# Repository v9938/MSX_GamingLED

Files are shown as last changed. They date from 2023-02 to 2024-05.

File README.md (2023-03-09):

# MSX Gaming LED Cartridge  

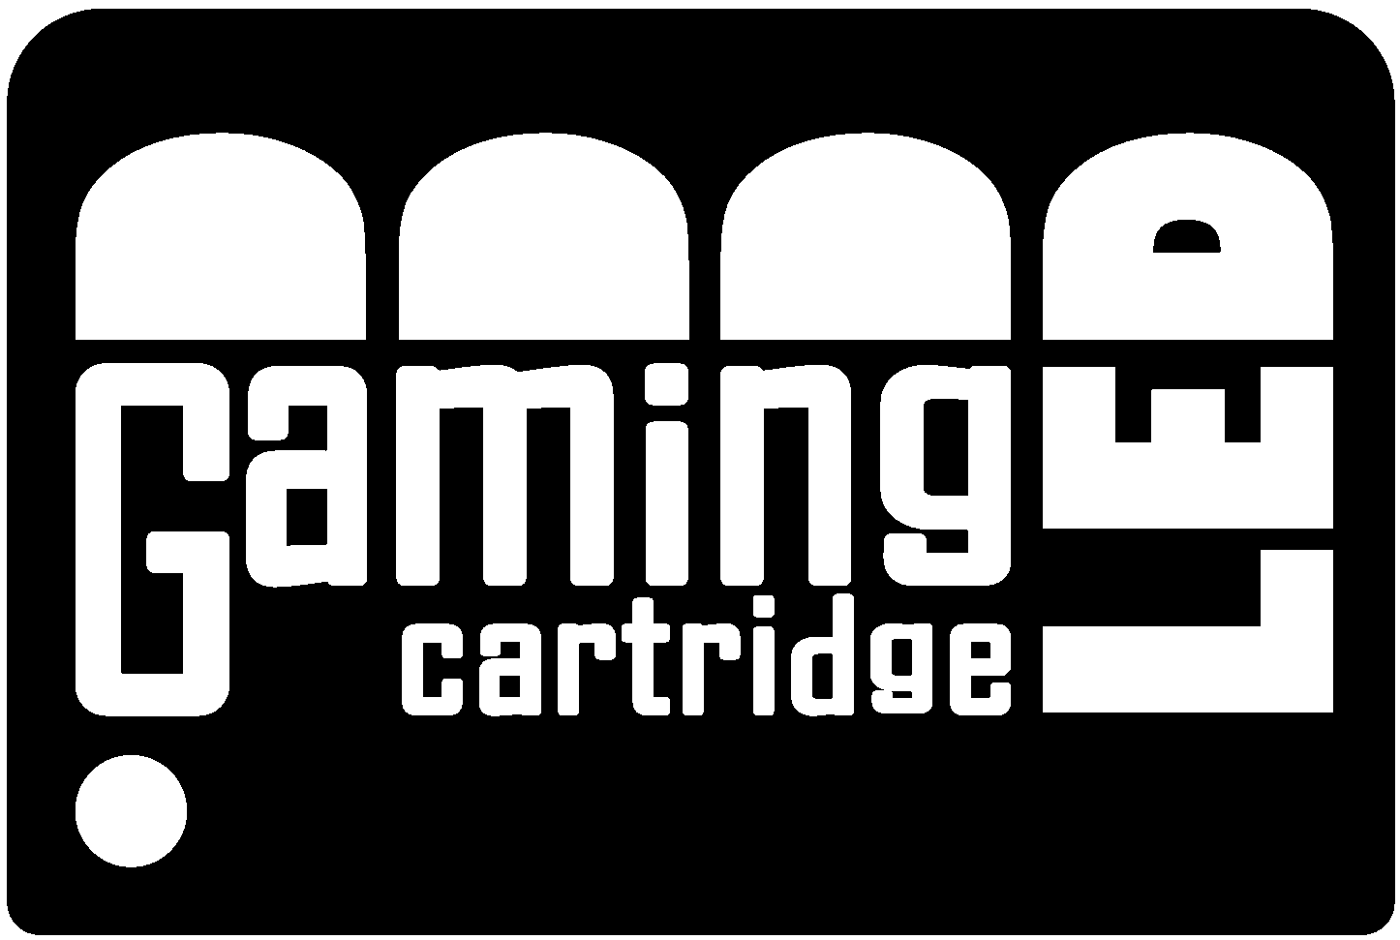
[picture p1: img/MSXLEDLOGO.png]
  

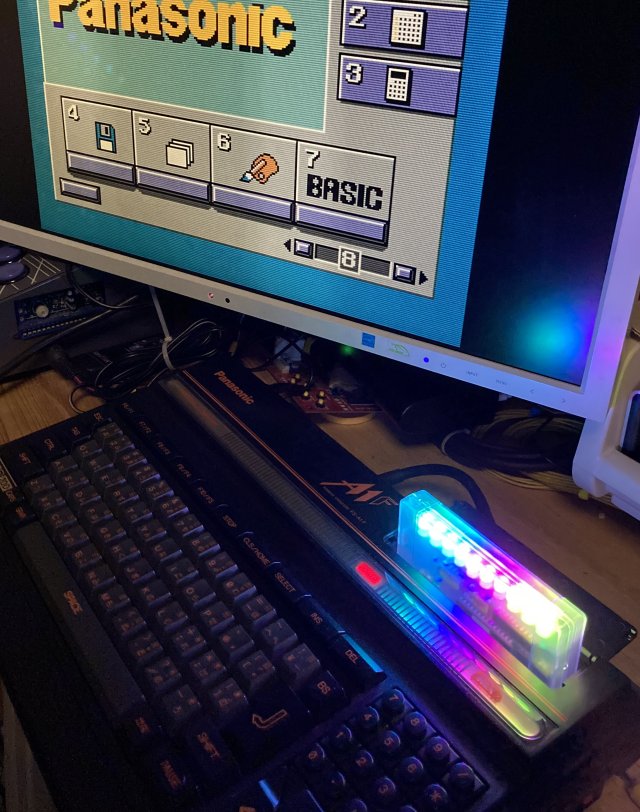
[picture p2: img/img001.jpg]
装置イメージ
  

MSX Gaming LED Cartridgeは10個のRGB LEDを搭載した、Party Nightなカセットです。  
MSX本体から拡張されたBASIC命令により10コのLEDは個別に点灯や色、点滅などのコントロールができ、  
本体のコントロールなしで簡単なアニメーションをさせることができます。

## ■ 使用イメージ

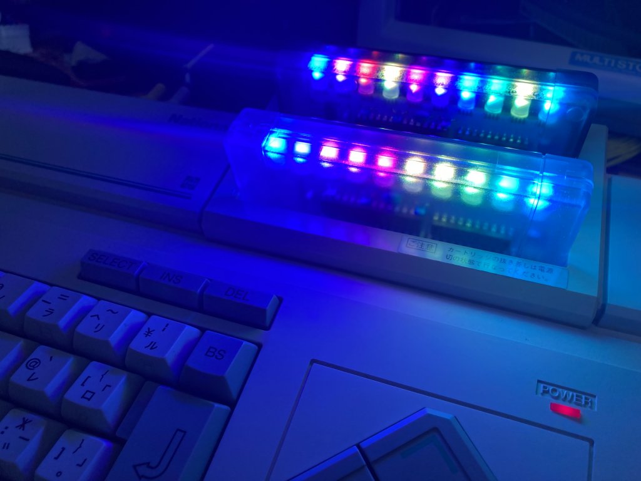
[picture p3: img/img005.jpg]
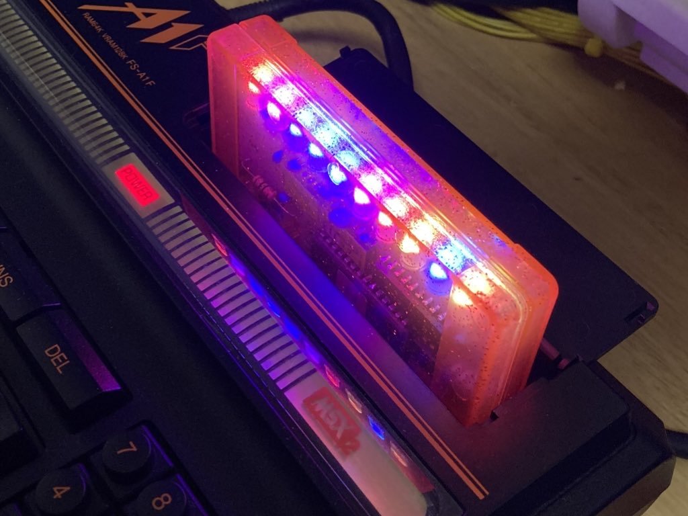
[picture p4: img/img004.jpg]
   
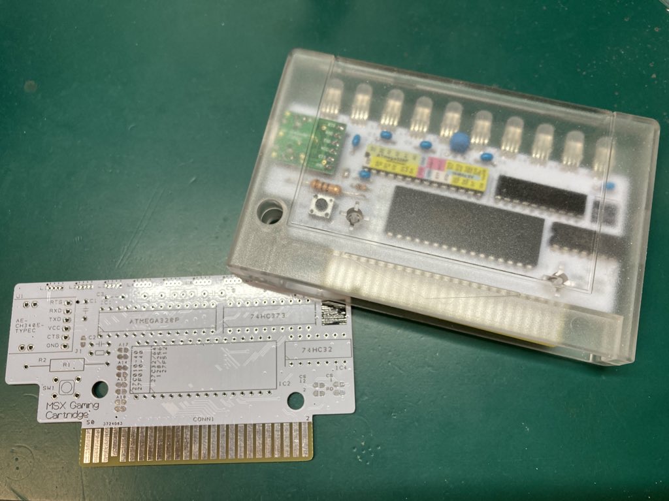
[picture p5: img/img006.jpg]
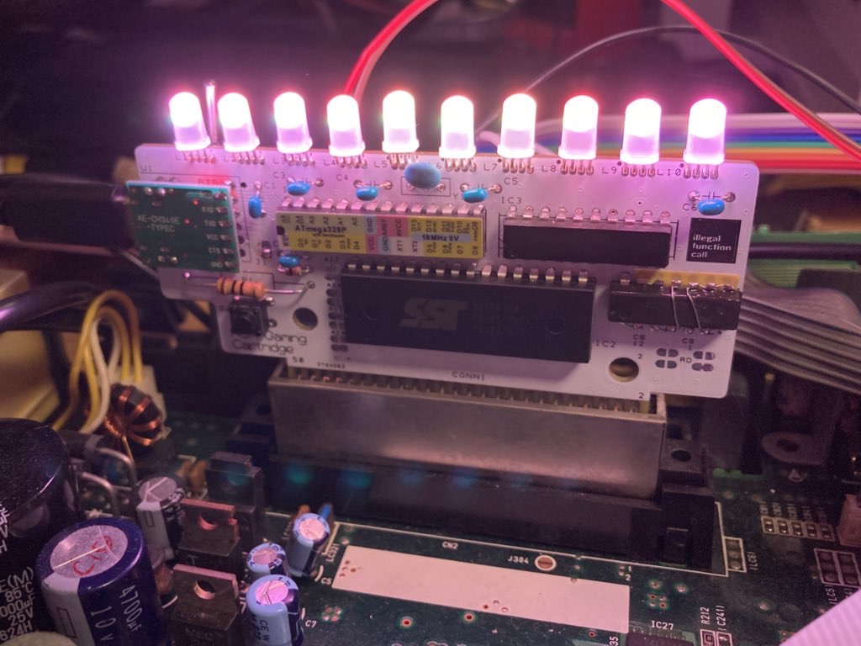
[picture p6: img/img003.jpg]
    

動画については下記URLを参照してください。  
<https://twitter.com/i/status/1623682455151706112>

## ■ 対応ソフトについて   
2023/2月現在下記ソフトが対応しています。

MGSP2(HRA!氏作)  
<https://github.com/hra1129/mgsp2/tree/main/dos2_version>  

## ■ 頒布について   

本製品は半田付けが必要なキット形式の頒布になります。  

Boothおよび家電のKENちゃんにて近日販売予定です。  
(Boothの発送は、週末にまとめて発送になるため、お急ぎの方は他ショップを利用ください)

配布の形態は、下記3形態になります。  

#### フルキット（基板 ＋ プログラム書き込み済みEPROM ＋その他パーツ）
必要なパーツも、すべてセットになったキットです。  

#### 基板＋ROMセット（基板 ＋ プログラム書込済EPROM ＋秋月電子のお買い物メモ）  
基板とプログラム書込済のEPROMのセットです。その他のパーツは秋月電子などで揃える必要があります。  
AVRマイコンへのプログラム書き込みが必要ですのでArduinoの取り扱い経験が必要です。  

#### 基板のみ  
基板単体です。(Boothのみ取り扱い予定)

## ■ 頒布先   

### 家電のKENちゃん  

全パーツ入りセット
<https://www.kadenken.com/view/item/000000001542?category_page_id=ct169>

ROM+基板のみ
<https://www.kadenken.com/view/item/000000001541?category_page_id=ct169>

### Booth: (週１回の発送)  

未定

## ■ BASIC拡張命令およびプログラムからの制御方法について

下記仕様書を参照ください。  

[LED拡張BASIC仕様書](./EXBASIC/led_exbasic.md)  
[MSXLED仕様書](./EXBASIC/msxled_bios.md)

使い方のサンプルは下記を参照してください。  
[BASIC Game Sample](https://github.com/v9938/MSX_GamingLED/tree/main/SampleGame)  
[BASIC/MSX-DOS Sample](https://github.com/v9938/MSX_GamingLED/tree/main/SampleApplication)  

## ■ 組み立て説明書について  
下記を参照ください。  

[組み立て説明書](./AssemblyManual/Assembly.md)

## ■ 対応カートリッジシェルについて
KONAMI基板に対応しているシェルが使用できます。  
当方が頒布しているRGRさんおよび韓国製のCartridge Shellで使える事を確認しています。  
委託先で購入が可能です。  

LEDの点灯が見えないので透明/半透明シェルを推奨します。

## ■ おまけソフト  

MSXTurboRでは[2]キーを押す事で非対応ソフトをR800高速モードで起動させることが可能です。  
ROMカセットで使用する場合、スロット番号の若い方に本カセットを挿入してください。  

## ■ 本機の仕様について

|仕様  | 詳細 |
| - | - |
| 対応規格 | MSX標準スロット規格 |
| 使用LED | PL9823/YF923 x10 |
| 搭載マイコン | Atmel ATMEGA328P (Arduino 5v 16MHz仕様) |
| 定格 | 5V 250mA |

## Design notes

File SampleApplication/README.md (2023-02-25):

# BASIC/MSX-DOS Sample program  
MSXLEDのBASICとMSX-DOSのサンプルプログラムです。

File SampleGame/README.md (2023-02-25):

# BASIC Game Sample program  
MSXLEDのBASICサンプルプログラムです。

あぶり６８００(@aburi6800)さんのGalaxy Zoneを使わせてもらいました。  
<https://github.com/aburi6800/msx-GalaxyZone>

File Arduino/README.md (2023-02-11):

# ATMEGA328Pプログラム
IC1 ATMEGA328Pのプログラムです。Arduino環境で作成されています。  

HEXファイルを書き込み時のFuse設定は下記の通りです。  
FUSE LOW  = 0xFF  
FUSE HIGH = 0xD6  
EXTENED FUSE = 0xFD  
LOCK BIT = 0xCF  

RGB LEDのライブラリとして、Indoor CorgiさんのALED-AddressableRGB-Libraryを使わせていただいています。

[GitHub](https://github.com/IndoorCorgi/ALED-AddressableRGB-Library)  
[Indoor CorgiさんのアドレサブルRGB LED解説](https://www.indoorcorgielec.com/resources/アドレサブルrgb/)  

より複雑な発光パターンを作成したい場合は上記内容を参照ください。

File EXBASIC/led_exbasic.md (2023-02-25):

# 拡張BASICコマンドの解説  
  
##拡張されるBASICのコマンドについて  
Cartridgeに搭載されているROMにて、以下の命令が拡張されます。  
  
各コマンドは処理完了までには数ms程度の時間がかかります。  
命令側でWait処理をいれていません。内部にBufferを持っていて順次処理をしていきます  
が、一度に送信しすぎるとCMDをロストする場合があるので注意してください。  
  
# MSXLED 拡張命令  
## CALL LED_DEBUG(<0-1>)  

### 機能   
LED DEBUG UARTを表示を有効化します。  

### 引数  
0 : デバッグメッセージ OFF  
1 : デバッグメッセージ ON  
  
## CALL LED_OFF  
  
### 機能   
LEDを消灯します。  
  
## CALL LED_DRAW  
  
### 機能   
LEDを描画します。  
  
## CALL LED_POS (\<led location 0-9>)  
### 機能    
描画するLEDのポジションを設定します。左から0,1,2...になります  

### 引数  
led location = 制御するLEDの位置(0-9)

## CALL LED_PT (\<pattern>)  
### 機能    
描画するLEDパターンを定義します。  

### 引数  
pattern = LEDの表示パターン  
0 : パターンSingle ... 全LED単一色の塗り潰しです。  
1 : パターンGrad   ... 色相グラデーションパターン1 (100%パターン)  
2 : パターンSym    ... 色相グラデーションパターン2 (50%パターン)  
3 : パターンPoint1 ... LED1灯のみ光らせるパターン(他は消灯)  
4 : パターンPoint2 ... LED1灯のみデータ更新するパターン(他は前の状態を維持)  

## CALL LED_DEMO (\<pattern>,[End Pattern],[Demo time])  

### 機能    
LEDのデモを実行します。  

### 引数  
pattern = デモパターンの指定  
0 :    パターンSingle ... 全LED単一色の塗り潰しです。  
1 :    パターンGrad   ... 色相グラデーションパターン1 (100%パターン)  
2 :    パターンSym    ... 色相グラデーションパターン2 (50%パターン)  
3 :    パターンPoint1 ... LED1灯のみ光らせるパターン(他は消灯)  
4 :    パターンPoint2 ... LED1灯のみデータ更新するパターン(他は前の状態を維持)  
5～9 : ユーザパターン ... ユーザparameter0-4で保存した値  
  
End Pattern =  終了パターン番号を指定、省略した場合はシングルパターンになります  
  
Demo time = パターンの切り替え時間を指定(0-127)、省略した場合は10秒で切り替わります。  

## CALL LED_DEMOON  
  
### 機能    
現在の設定値でLEDのデモを設定します。  
設定すると、電源を入れておくと次回も同じデモが勝手にスタートします。  
  
## CALL LED_DEMOOFF  
  
### 機能    
LEDのデモ設定を切ります。  
  
## CALL LED_SAVEINIT  
  
### 機能    
LEDのユーザ設定値を初期値に戻します。  
  
## CALL LEDC_RGB (r,g,b)  

### 機能    
RGB値でカラーコードを設定します。システム内部ではHSV方式で管理しているため  
CALL LEDC_HUE/SAT/VALで設定される値は上書きされます。  

### 引数  
r = Red   (0-127)  
g = Green (0-127)  
b = Blue  (0-127)  

## CALL LEDC_HUE(\<hue>)  

### 機能    
HSV方式の色相を設定します。  

### 引数  
hue = 色相 0-360  

## CALL LEDC_SAT (\<sat>)  

### 機能    
HSV方式の色の濃さを設定します。  

### 引数  
sat = 色の濃さ 0-100  
  
## CALL LEDC_VAL (\<val>)  

### 機能    
HSV方式の明るさを設定します。  

### 引数  
val = 明るさ 0-100  
  
## CALL LEDPT_HUE(\<hue>)  

### 機能    
グラデーションパターン時の色相の変化量を指定します。  

### 引数  
hue = 色相 0-360  

## CALL LEDPT_REP (0-10)  
### 機能    
描画するLEDの模様の繰り返し回数を設定します  
  
## CALL LEDTEST (\<val>)  

### 機能    
テスト用当該スロットに1Byteデータ書き込みを実施します。  
通信の仕様上7bit分しか通信できません  

### 引数  
val = 0-127  

## CALL LED_REAL (\<val>)  

### 機能    
クロスチェック用のテストコマンド、  
Debugを有効にすると内部値がUARTに出力されます  

### 引数  
val = 0-360  
  
## CALL LEDA_ON  

### 機能    
今設定しているparameter値に合わせてアニメーションを実行します。  
  
## CALL LEDA_OFF  

### 機能    
アニメーションを停止とします。(LEDは、点灯状態)  
  
## CALL LEDA_HUE (\<mode>,\<val>)  

### 機能    
16ms毎のHUE値の変化量と変化の仕方を設定します。  
  
### 引数  
mode = 
0: 値がMAXなったら0に戻ります  
1: 値がMAXになったマイナスされ、0になると元に戻ります。  

val =  
HUE値 -360.000-360.000  

## CALL LEDA_SAT (\<mode>,\<val>)  

### 機能    
16ms毎のSAT値の変化量と変化の仕方を設定します。  

### 引数  
mode =  
0: 値がMAXなったら0に戻ります  
1: 値がMAXになったマイナスされ、0になると元に戻ります。  

val = SAT値 -100.000-100.000  

## CALL LEDA_VAL (\<mode>,\<val>)  

### 機能    
16ms毎のVAL値の変化量と変化の仕方を設定します。  
  
### 引数  
mode =   
0: 値がMAXなったら0に戻ります  
1: 値がMAXになったマイナスされ、0になると元に戻ります。  

val = VAL値 -100.000-100.000  
  
## CALL LEDA_POS (\<mode>,\<val>)  

### 機能    
16ms毎のPOS値の変化量と変化の仕方を設定します。  
  
### 引数  
mode =  
0: 値がMAXなったら0に戻ります  
1: 値がMAXになったマイナスされ、0になると元に戻ります。  

val = POS値 -100.000-100.000  
  
## CALL LEDPT_SAT (\<val>)  

### 機能    
LEDのグラデーションパターン時のSAT値の変化量を設定します。  
  
### 引数  
val = SAT値の変化範囲指定 0-100
  
## CALL LEDPT_VAL (\<val>)  
  
### 機能    
LEDのグラデーションパターン時のVAL値の変化量を設定します。  

### 引数  
val = VAL値の変化範囲指定 0-100

## CALL LEDPT_AVAL (\<val>)  

### 機能    
LED patternのVAL100%時の明るさを設定します。  

### 引数  
val = 全体の明るさ 0-100

## CALL LEDPT_SAVE (\<val>)  

### 機能    
ユーザパターンをEEPROMに保存します。  
保存した値はDEMOパターン5-9として使用できます。  
  
### 引数  
val = 保存番号0-4   
  
## CALL LEDPT_LOAD (\<val>)  

### 機能    
ユーザパターンをEEPROMからロードします。  

### 引数  
val = 保存番号0-4   
  
## CALL LEDA_PAUSE(\<Value>)  

### 機能    
Animation機能を一次的に停止します。  
停止時のLEDC系とLED_POS値が保存され、再開時の戻します。  
LEDPT系のParameterは保存されないので注意してください。
  
### 引数
val =   
0: Animation動作再開  
1: Animation動作PAUSE  
  
# V1.40以降対応した命令  
## CALL LEDPT_RGB (\<POS>,\<R>,\<G>,\<B>)  

### 機能    
RGB形式でLEDのポジションと色を一括で指定します。  

### 引数  
POS = LEDの位置 0-9  
R/G/B = RGBでの色指定0-127  
※色設定は整数値になります。

## CALL LEDPT_HSV (\<POS>,\<H>,\<S>,\<V>)  

### 機能    
HSV形式でLEDのポジションと色を一括で指定します。  

### 引数  
POS = LEDの位置 0-9  
H = Hue値 (0-360)  
S = Sat値 (0-100)  
V = Val値 (0-100)  
※色設定は整数値になります。

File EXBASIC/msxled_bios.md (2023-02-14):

# BASIC以外から扱う場合の情報  

## LED Gamming Cartridgeの通信フォーマット  
000h 043h 000h CMD番号 ... の順番でこのCartridgeのスロットに書き込むことで実行する。  
000hの部分はbit0を0のデータであれば何でも良いです。  

書き込みアドレスはBIOSでは07F00hを使っています。  
回路上はアドレスをデコードをしていないので書き込みアドレスは適当でも動作します。  

bit0を1にしたデータを取り込む仕様なので、有効データは7bit分です。  
8bit分のデータを送信する場合は ([bit6-0],1),(000000b,[bit7],1)に分けて送信が必要です。  
Data-Data間は10us程度のWaitが必要です、そのためLDIRは使えません。  

各コマンドは処理完了までには数ms程度の時間がかかります。  
内部にBufferを持っていて順次処理をしていきますが、  
64Byte分なので一度に送信しすぎると、コマンドをロストするので注意してください。  

## LED Cartridgeの識別子  
0x4010～の文字列が'MSXLED"というスロットを探してください。  
当該スロットが本Cartridgeになります。  

## Service Routineについて  
0x4020にCMD送信のServiceルーチンが置いてあります。  
### LEDコマンド送信 (4020h)  

<function>  
LEDCartridgeにコマンドを送信します。  
  
	A   実行するコマンド
	B   コマンドサイズ（送信データサイズ）
	HL  送信CMDバッファーの先頭アドレス  

	破壊されるレジスタ：  すべて  

各コマンドの引数は下記フォーマットでRAM上に置き、HLレジスタに先頭アドレス、  
Aレジスタにはコマンド、Bレジスタに送信データサイズをセットしCALLすれば、LED Cartridgeにコマンドがセットされます。  
送信データは、0-127の数値であることが必要です。ただし、9Byte指定のみ4ByteのBCD floatフォーマットが引数です。

	1byte：無し  
	2byte：'[parameter1(7bit 0-127)]'  
	4byte：'[parameter1(7bit 0-127)] [parameter2(7bit 0-127)] [parameter3(7bit 0-127)]'  
	9byte：'[BCD float数値(4byte)]' ※内部で8Byteに変換します  
	その他：データの並び順に送信します。

## コマンド番号一覧  

|コマンドラベル  | コマンド番号 | 命令長 | 内容 |
| - | - | - | - |
|c_cmd_st | 043h	| - | CMDスタート識別子（Serviceルーチン仕様時は不用）  
|  |  |  |  |
|cl_debugen	|		001h | 1Byte | LED Debug UART On |
|cl_off | 003h | 1Byte | LED OFF/DEMO STOP |
|cl_draw | 005h | 1Byte | LED draw |
|cl_pos | 007h | 2Byte | LED position setting |
|cl_pat | 009h | 2Byte | LED pattern setting |
|cl_eepinit  | 00bh | 1Byte | EEPROM Init |
|cl_demo | 00dh | 4Byte | LED DEMO |
|cl_real | 00fh | 9Byte | LED REAL Test |
|  |  |  |  |
|cl_c_rgb | 011h | 4Byte | RGB Coler code |
|cl_c_hue | 013h | 9Byte | HSV Coler code hue |
|cl_c_sat | 015h | 9Byte | HSV Coler code sat |
|cl_c_val | 017h | 9Byte | HSV Coler code val |
|cl_p_hue | 019h | 9Byte | Gradation Pattern hue step value |
|cl_p_rep | 01bh | 2Byte | LED pattern repeat value |
|cl_a_ena| 01dh | 1Byte | LED Animation enable |
|cl_a_dis | 01fh | 1Byte | LED Animation disable |
|  |  |  |  |
|cl_a_hue | 021h | 9Byte | HSV Animation hue |
|cl_a_sat | 023h | 9Byte | HSV Animation sat |
|cl_a_val | 025h | 9Byte | HSV Animation val |
|cl_a_pos | 027h | 9Byte | HSV Animation pos |
|cl_a_modeh  | 029h | 2Byte | HSV AnimationMode hue |
|cl_a_modes  | 02bh | 2Byte | HSV AnimationMode sat |
|cl_a_modev  | 02dh | 2Byte | HSV AnimationMode val |
|cl_a_modep  | 02fh | 2Byte | HSV AnimationMode val |
|  |  |  |  |
|cl_p_sat	| 031h | 9Byte | Gradation Pattern sat step value |
|cl_p_val	| 033h | 9Byte | Gradation Pattern val step value |
|cl_p_aval	| 035h | 9Byte | Gradation Pattern all val value  |
|cl_ee_set	| 037h | 2Byte | EEPROM Write |
|cl_ee_get	| 039h | 2Byte | EEPROM Read |
|cl_ee_cnf	| 03bh | 1Byte | EEPROM Config set |
|cl_a_pause  | 03dh | 2Byte | AnimationMode pause |
|cl_p_rgb	| 03fh | 5Byte | (V1.3～) Color Parameter set (RGB format) |
|  |  |  |  |
|cl_p_hsv	| 041h | 6Byte | (V1.3～)  Color Parameter set (HSV format) |
|cl_null	| 043h | 1Byte |  (V1.3～) NULL CMD (Start CMDと共通なのでNULLにしている）  |
|cl_p_rgball | 045h | 31Byte |  (V1.4～) ALL Color Parameter set & Draw(RGB)  |
|cl_p_hsvall | 047h | 41Byte |  (V1.4～) ALL Color Parameter set & Draw(HSV) |

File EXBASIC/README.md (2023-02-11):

# 拡張BASICプログラム  
拡張BASICプログラムのソースです。  
コンパイルにはMicrosoft M80/L80が必要です。  

できあがったHEXファイルをEPROMに書き込めば動作しますが、  
現在頒布中のRevB基板では基板の設定都合でEPROMの4000h以降に配置される様に書き込んでください。

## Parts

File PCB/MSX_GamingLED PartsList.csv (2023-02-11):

Ref Name | Mfr. Part No. | Qty | 通販コード | 商品名(秋月電子) | Price | 備考
U1 | 5V USB to Serial Unit | 1 | K-14745 | AE-CH340E-TYPEC | 550 | Arduinoプログラム書き込み時のみ使います。 類似品を持っている場合は購入不要
U1 | Pin Header 6P | 1 | C-05336 | ピンヘッダ （Ｌ型） １×６ （６Ｐ） | 10 | Serialユニットを取り外し式にする場合は必要
IC1 | Microchip ATMEGA328P-PU | 1 | I-12774 | Ａｒｄｕｉｎｏ Ｂｏｏｔｌｏａｄｅｒ書込済 （５Ｖ １６ＭＨｚ仕様） ＡＴｍｅｇａ３２８Ｐ | 400 | Bootloaderが自力で書ける人は単体デバイスでOK
C1-6 | Murata RDER71H104K0K1H03B | 6 | P-13582 | 積層セラミックコンデンサー ０．１μＦ５０Ｖ Ｘ７Ｒ ２．５４ｍｍ （１０個入） | 100
IC4 | 74HC00 | 1 | I-14052 | ４回路２入力ＮＡＮＤ Ｕ７４ＨＣ００Ｌ－Ｄ１４－Ｔ | 20 | I-10856 TC74HC00APでもOK
IC3 | 74HC373 | 1 | I-13348 | ８回路入３ステートラッチ ７４Ｆ３７３ （１０個入） | 100
Y1 | Murata CSTLS16M0X53-B0 | 1 | P-09576 | セラミック発振子（セラロック） コンデンサー内蔵タイプ １６ＭＨｚ | 35
L1-10 | PL9823-F5 | 10 | I-08411 | マイコン内蔵ＲＧＢＬＥＤ ５ｍｍ ＰＬ９８２３－Ｆ５ | 400 | 8mm PL9823-F8でもOK
R2 | Yageo CFR-12JT-52-10K | 1 | R-16103 | カーボン抵抗（炭素皮膜抵抗） １／６Ｗ１０ｋΩ （１００本入） | 100
R1 | TE ROX1SJ100R | 1 | R-07956 | カーボン抵抗（炭素皮膜抵抗） １Ｗ１０Ω （１００本入） | 200 | 1W以上の抵抗を必ず使ってください。
IC2 | TOSHIBA TMM27256AD-20 | 1 | - | TOSHIBA TMM27256AD-20 | 0 | キットに添付(基板だけ購入を除く）
SW1 | OMRON B3F-1020 (Max 7mm height) | 1 | P-11243 | タクトスイッチ アルプス製 ※余分な足を切って使ってください | 10 | オプション： スイッチの高さに注意してください P-03647 タクトスイッチはケースに入らないので注意してください
 |  |  |  | Sub-total: | 1925

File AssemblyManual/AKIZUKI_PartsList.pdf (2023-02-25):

| Ref | 通販コード 秋葉原店棚番号 | 商品名 | Qty | 参考価格 (23’/2) | 備考
□ U1 | K-14745 | 1F売場 05 | AE-CH340E-TYPEC | 1
¥550 類似品を持っている場合は購入不要
□ U1 | C-05336 | 1F 12 売場 キャビネット下段 | ピンヘッダ　（Ｌ型）　１×６　（６Ｐ） | 1
¥10 Serialユニットを取り外し式にする場合は必要
□ IC1 | I-12774 | 1F 30 スチールラック売場 | Ａｒｄｕｉｎｏ　Ｂｏｏｔｌｏａｄｅｒ書込済 （５Ｖ　１６ＭＨｚ仕様） ＡＴｍｅｇａ３２８Ｐ | 1 | ¥400 5V仕様を購入すること Bootloaderが自力で書ける人は単体デバイスでOK
□ C1-6 P-13582 | 1F 22 売場 3段目 | 積層セラミックコンデンサー ０．１μＦ５０Ｖ　Ｘ７Ｒ　２．５４ｍｍ　（１０個入） | 1 | ¥100
□ IC4 | I-14052 | 1F 13 売場 キャビネット下段 | ４回路２入力ＮＡＮＤ Ｕ７４ＨＣ００Ｌ－Ｄ１４－Ｔ | 1 | ¥20 I-10856　TC74HC00APでもOK
□ IC3 | I-13348 | 1F 13 売場 キャビネット下段 | ８回路入３ステートラッチ ７４Ｆ３７３　（１０個入） | 1 | ¥100
□ Y1 | P-09576 | 1F 13 売場 キャビネット下段 | セラミック発振子（セラロック） コンデンサー内蔵タイプ　１６ＭＨｚ | 1 | ¥35
□ L1-10 I-08411 | 1F 25 売場 3段目 | マイコン内蔵ＲＧＢＬＥＤ ５ｍｍ　ＰＬ９８２３－Ｆ５ | 10
¥400 8mm　PL9823-F8でもOK
□ R2 | R-16103 | 1F 15 売場 キャビネット下段 | カーボン抵抗（炭素皮膜抵抗） １／６Ｗ１０ｋΩ　（１００本入） | 1 | ¥100
□ R1 | R-07956 | 1F 14 売場 キャビネット上段 | カーボン抵抗（炭素皮膜抵抗） １Ｗ１０Ω　（１００本入） | 1 | ¥200 1W以上の抵抗を必ず使ってください。
□ SW1 P-11243 | 1F 08 売場 キャビネット下段 | タクトスイッチ　アルプス製 ※余分な足を切って使ってください | 1 | ¥10 スイッチの高さに注意してください P-03647 タクトスイッチはケースに入らないです。

## 秋月電子でのお買い物リスト

### 見つからない部品は店員さんに場所を聞きましょう

詳細を見たい場合はこちらを参照

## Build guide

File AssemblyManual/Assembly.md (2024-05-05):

# MSX Gaming LED Cartridge 組み立てマニュアル

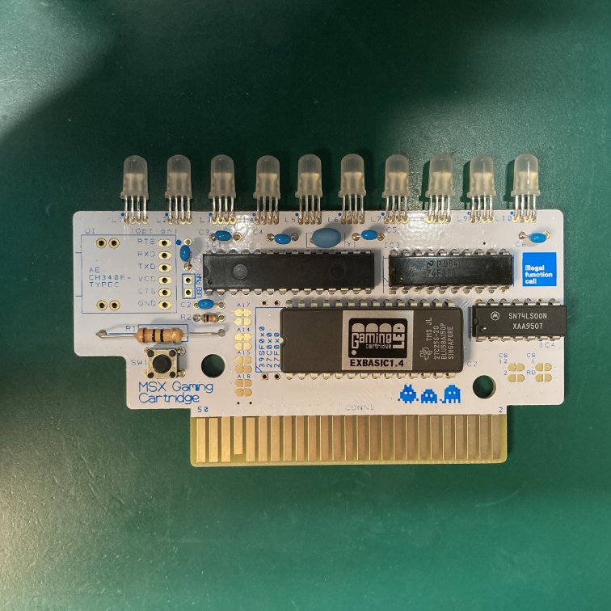
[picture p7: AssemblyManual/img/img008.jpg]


## パーツ一覧

### ■フルキット版  

組み立てに必要なパーツは下記の通りです。  
最低限の動作に必要なパーツは同梱してあります。不足があった場合は連絡お願いします。  
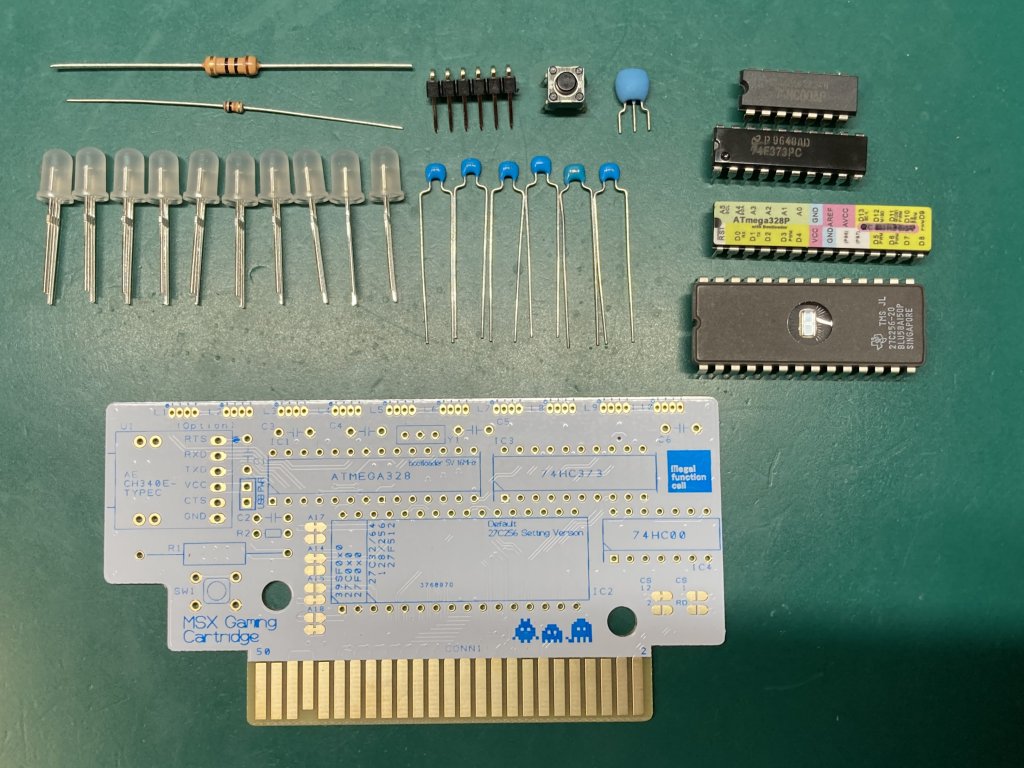
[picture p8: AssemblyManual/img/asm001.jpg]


### 付属部品一覧

|Ref No|Part Name.|Qty|備考|
| :- |  :- |  :- |  :- |
|－|専用PCB|1||
|U1|Pin Header 6P|1|通常は未実装、Serialユニット接続時に使用|
|IC1|Microchip ATMEGA328P-PU|1|Bootloaderとファームウェア書き込み済|
|C1-6|積層セラミックコンデンサー0.1uf 50V|6||
|IC4|TC74HC00AP<BR>(同等品)|1|　|
|IC3|TC74HC373P<BR>(同等品)|1|　|
|Y1|村田 CSTLS16M0X53-B0|1|セラロック１６ＭＨｚ|
|L1-10|PL9823-F5|10|マイコン内蔵RGB LED 5mm |
|R2|100KΩ 1/6W|1||
|R1|10Ω 1W |1|　|
|IC2| 27C256または27C128<BR>(同等品) |1|拡張BASIC書き込み済
|SW1| OMRON B3F-1020 |1|

### ■ 基板＋EPROM版

基板の他に書き込みが難しいUV-EPROMが付属しています  

その他、部品は別途購入する必要があります。秋月電子で揃える事が可能です。  
通販コードを明記してありますので通販で揃えても良いと思います。  

AVRマイコンへのファームウェア書き込みが必要なのでArduinoの実行環境とUSBシリアルユニット必要です。  
また、Arduino Bootloaderの事前書き込みが必要です。（秋月電子では書き込み済を販売しています）  

### 付属部品一覧

|Ref No|Part Name.|Qty|備考|
| :- |  :- |  :- |  :- |
|－|専用PCB|1||
|IC2| 27C256<BR>(同等品) |1|拡張BASIC書き込み済

### 秋月電子お買い物リスト

下記パーツを一括で秋月電子のカートに入れる →[PartsCabi.netのページへ](https://partscabi.net/list/a1651c81-8f59-4dd2-ab42-5e0de5e76d7f)

|Ref No|通販コード|商品名(秋月電子)|Qty|参考価格(2023/2)|備考|
| :- |  :- |  :- |  :- |  :- |  :- |
|U1|K-14745|AE-CH340E-TYPEC|1|￥550|類似品を持っている場合は購入不要|
|U1|C-05336|ピンヘッダ　（Ｌ型）　１×６　（６Ｐ）|1|￥10|Serialユニットを取り外し式にする場合は必要|
|IC1|I-12774|Ａｒｄｕｉｎｏ　Ｂｏｏｔｌｏａｄｅｒ書込済（５Ｖ　１６ＭＨｚ仕様）ＡＴｍｅｇａ３２８Ｐ"|1|￥400|5V仕様を購入すること<BR>Bootloaderが自力で書ける人は単体デバイスでOK|
|C1-6|P-13582|積層セラミックコンデンサー０．１μＦ５０Ｖ　Ｘ７Ｒ　２．５４ｍｍ　（１０個入）|6|￥100||
|IC4|I-14052|４回路２入力ＮＡＮＤ　Ｕ７４ＨＣ００Ｌ－Ｄ１４－Ｔ|1|￥20|I-10856　TC74HC00APもOK|
|IC3|I-13348|８回路入３ステートラッチ　７４Ｆ３７３　（１０個入）|1|￥100||
|Y1|P-09576|セラミック発振子（セラロック）コンデンサー内蔵タイプ　１６ＭＨｚ|1|￥35||
|L1-10|I-08411|マイコン内蔵ＲＧＢＬＥＤ　５ｍｍ　ＰＬ９８２３－Ｆ５|10|￥400| PL9823-F8でもOK|
|R2|R-16103|カーボン抵抗（炭素皮膜抵抗）１／６Ｗ１０ｋΩ　（１００本入）|1|￥100||
|R1|R-07956|カーボン抵抗（炭素皮膜抵抗）１Ｗ１０Ω　（１００本入）|1|￥200|1W以上の抵抗を必ず使ってください。|
|SW1|P-11243|タクトスイッチ　アルプス製<BR>※余分な足を切って使ってください|1|￥10|スイッチの高さに注意してください<BR>P-03647 タクトスイッチはケースに入らないです。"|

## ■ 基板の組み立て

セオリー通り背の低い部品から半田付けしてください。  
ICソケットを使うとケースに入らなくなるので注意してください。  

### 1．カードエッジをマスキングテープなどで端子保護します（推奨）  

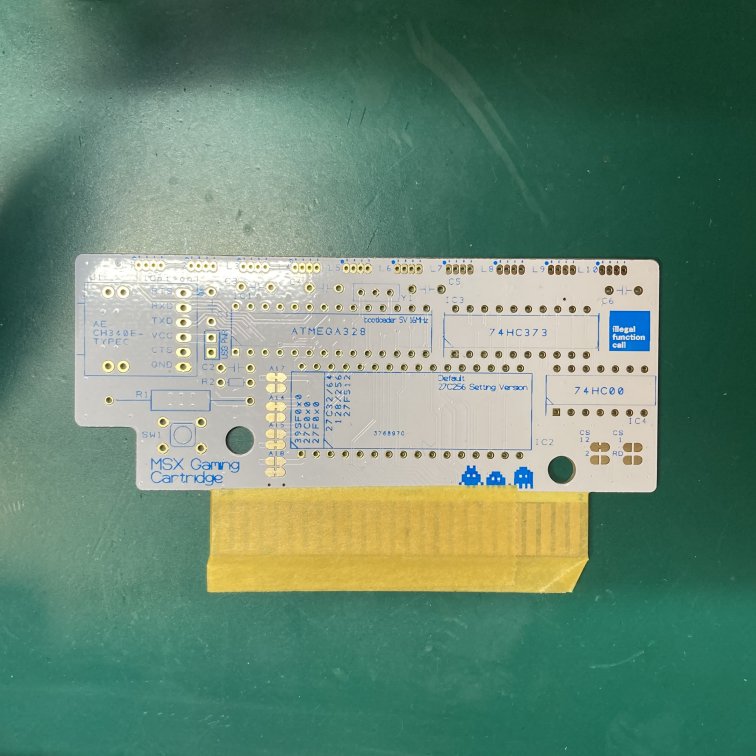
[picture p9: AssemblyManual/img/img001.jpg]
  

### 2．R2/C1-6を実装します  

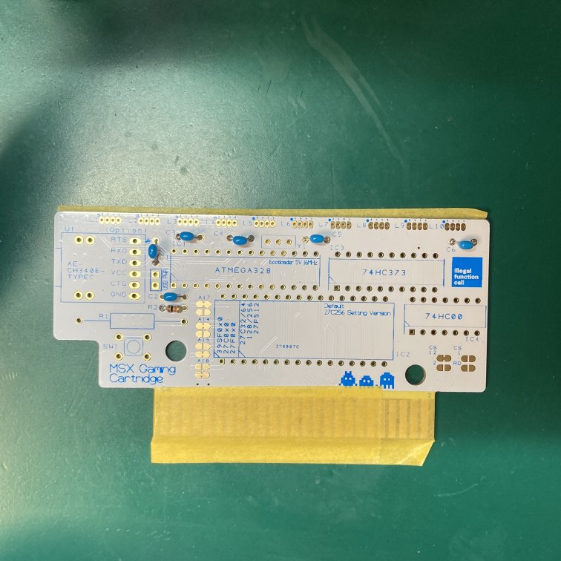
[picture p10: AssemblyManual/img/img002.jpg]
  

### 3．Y1/R1/SW1を実装します  

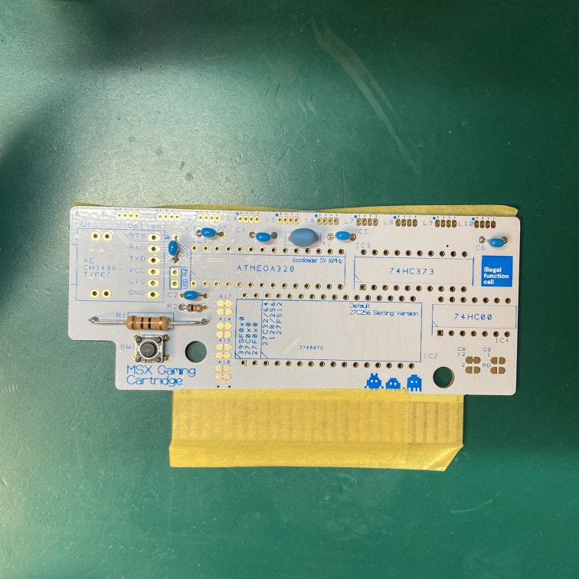
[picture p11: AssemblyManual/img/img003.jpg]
  

R1は多少発熱するので、PCBから多少浮かし実装してください。  
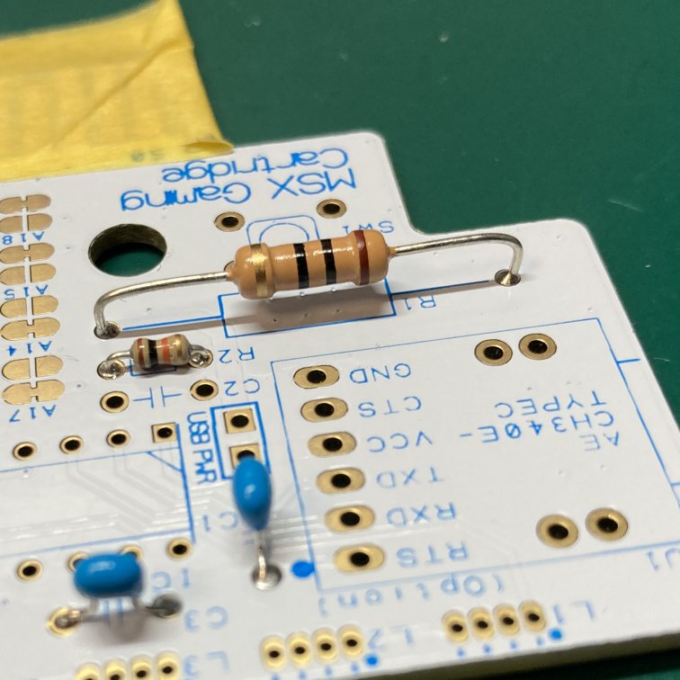
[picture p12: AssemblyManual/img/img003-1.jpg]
  

### 4．IC1-4を実装します  

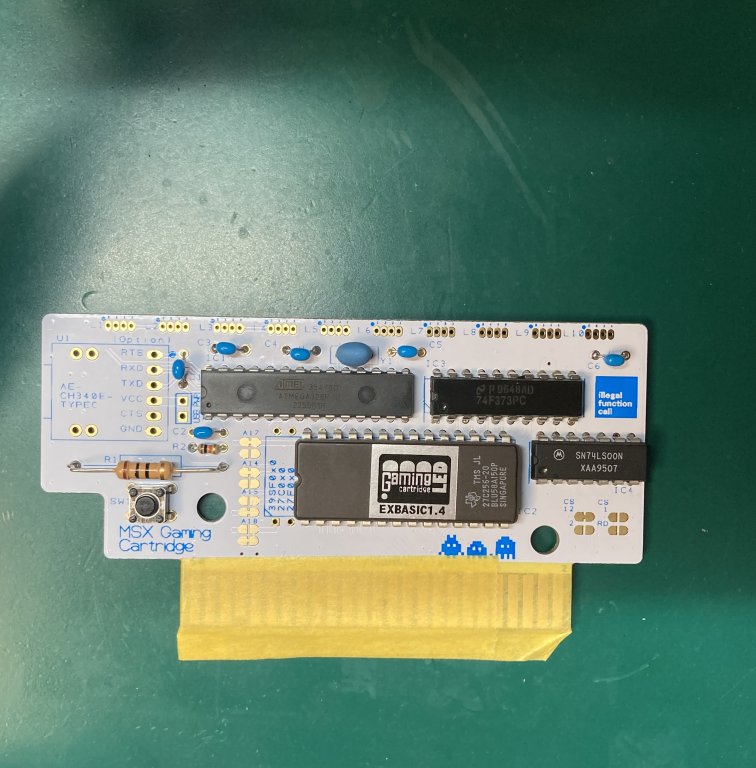
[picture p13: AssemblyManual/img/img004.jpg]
  

### 5．L1-10を実装します  

LEDの実装は後から曲げるやり方(左)と前もって曲げるやり方(右)があります。  
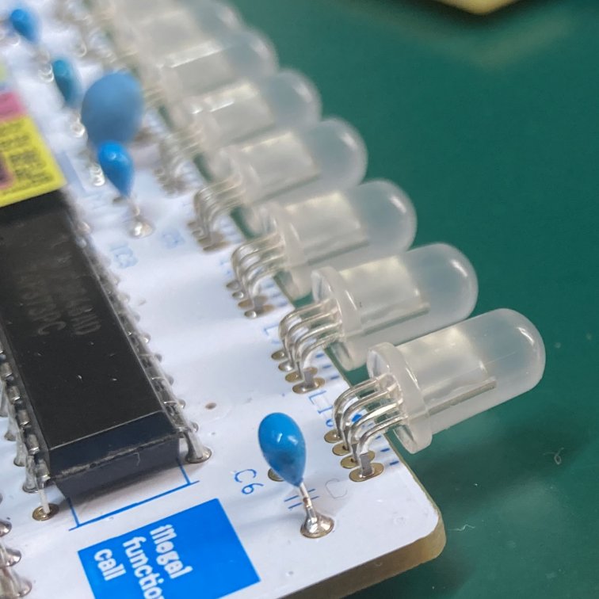
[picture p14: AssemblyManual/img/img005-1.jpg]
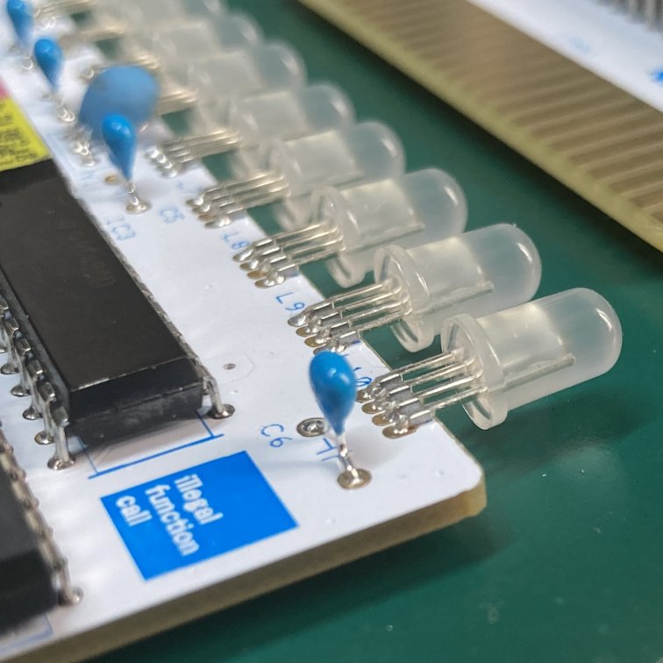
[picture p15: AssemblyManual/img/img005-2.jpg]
  

#### 後から曲げる場合

足が短い方向がDOT側(左)、欠けている側が右になります。  
仕上がりに影響があるので、実装時は膨らみが引っかかる所まで挿入してください。 
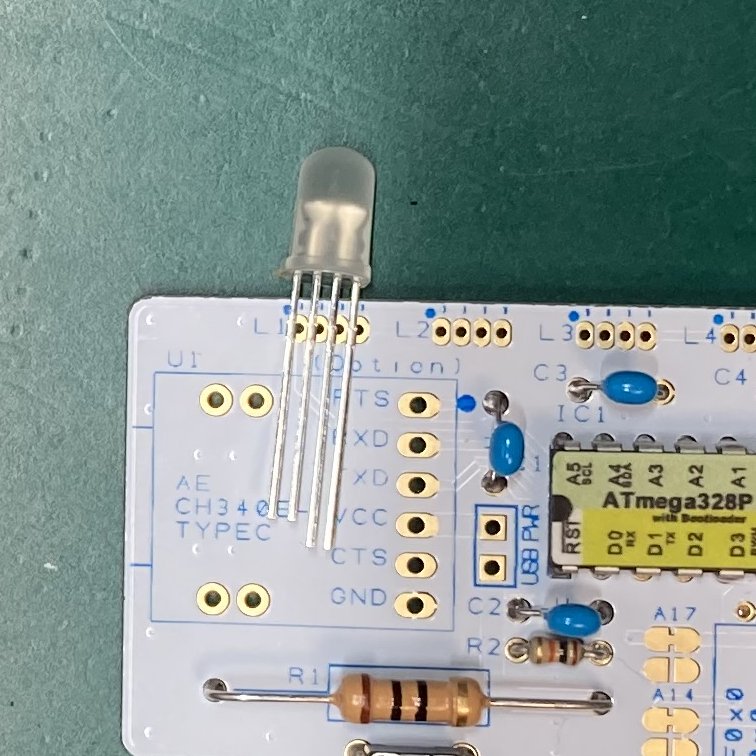
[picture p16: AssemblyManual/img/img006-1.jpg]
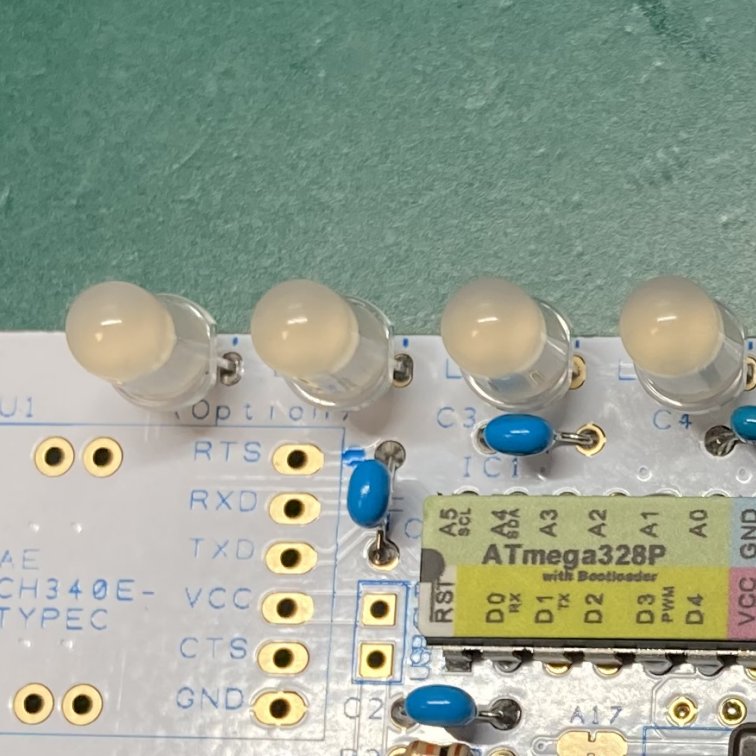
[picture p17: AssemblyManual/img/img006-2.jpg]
    

すべてのLEDが実装したら90度に曲げてください。根元から1mm程度の所で曲がります。  
曲げるときにできるだけ、それぞれの位置が揃う様にすると仕上がりが綺麗です。  
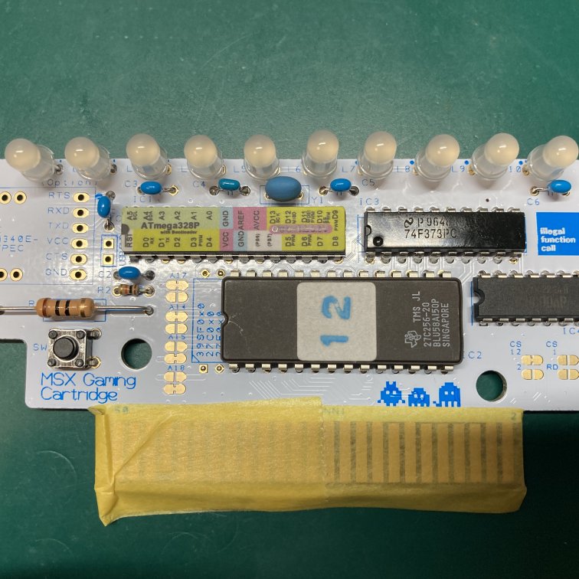
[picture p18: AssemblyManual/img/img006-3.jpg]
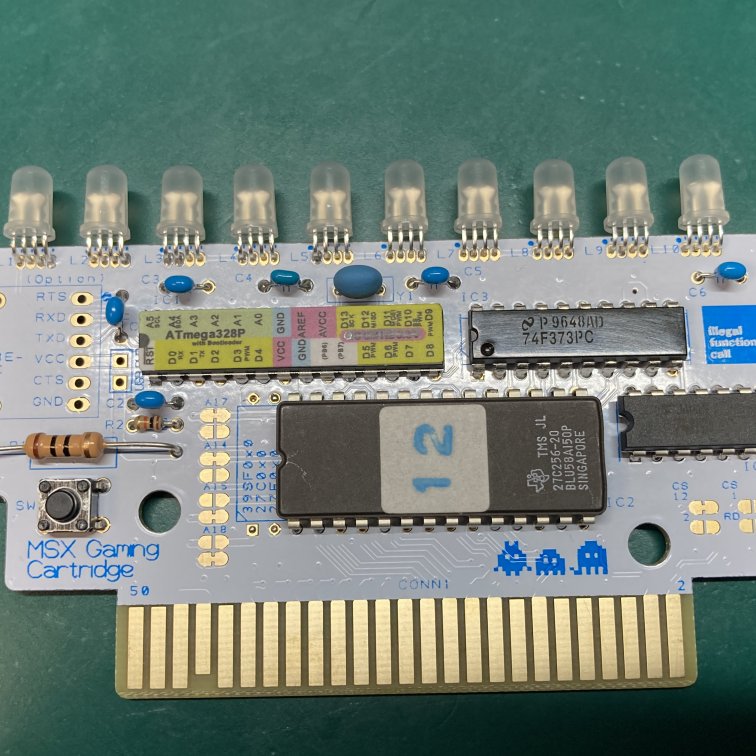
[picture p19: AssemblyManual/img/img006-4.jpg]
      

#### 先に曲げる場合

膨らみがある下であらかじめ足を90度に曲げておきます。  
足が短い方向がDOT側(左)、欠けている側が右になります。  
LEDの足が基板と同じ高さになる様に実装していきます。  
それぞれの位置が揃う様に調整しながら実装すると仕上がりが綺麗です。  
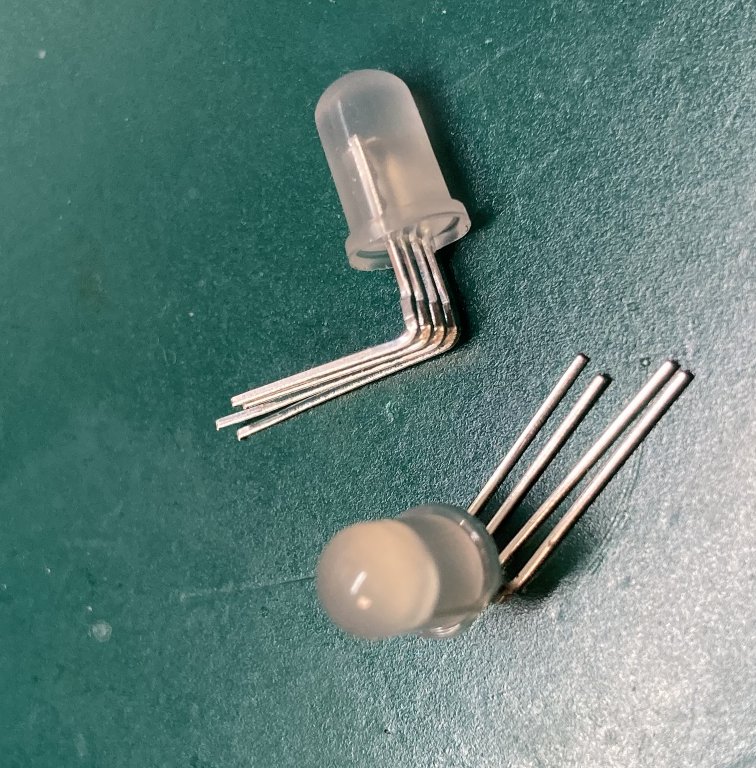
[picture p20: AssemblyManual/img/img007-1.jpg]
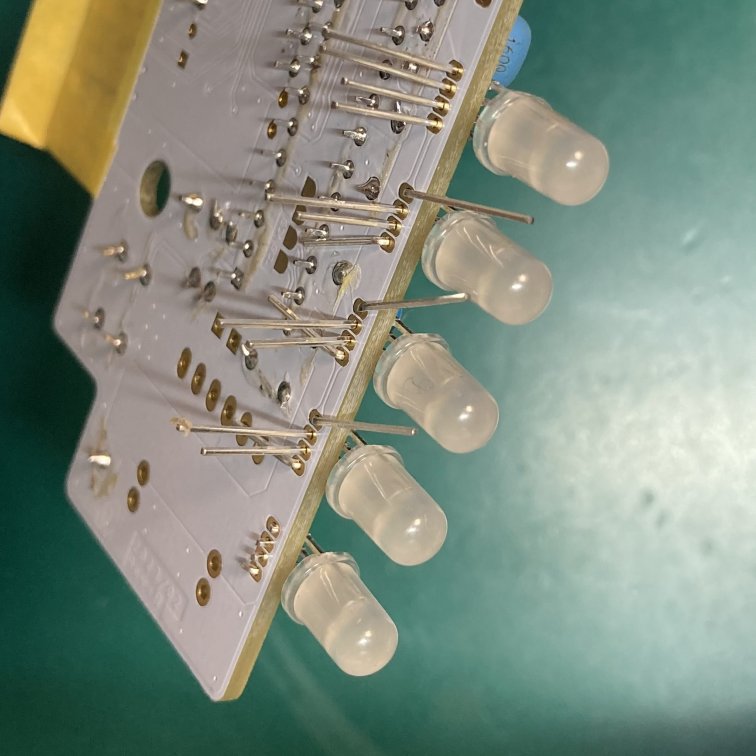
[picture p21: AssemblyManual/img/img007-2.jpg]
     

### 6．U1にシリアルユニットまたはジャンパを実装します(オプション)  

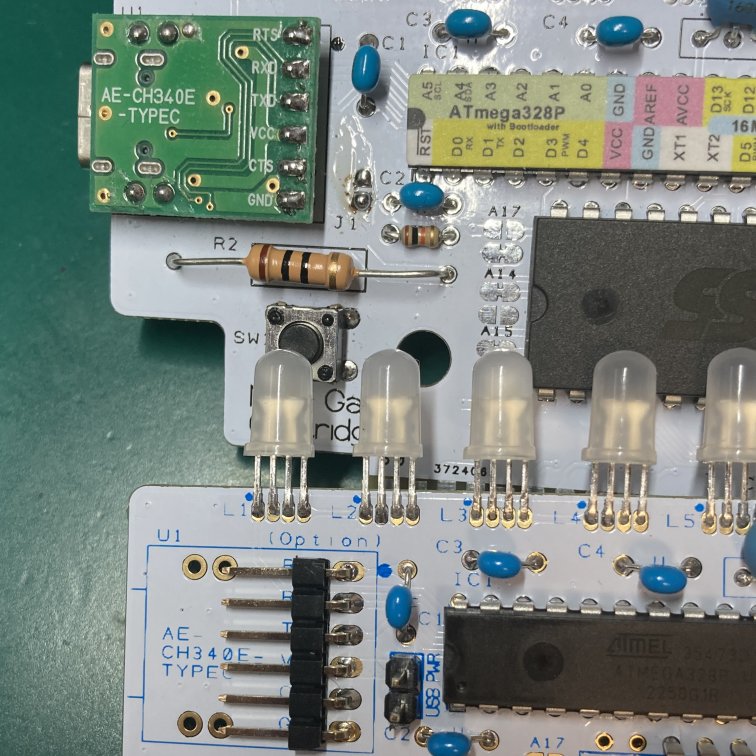
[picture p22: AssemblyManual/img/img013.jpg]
  

### 7．完成！  

組み立て完了です。実機に挿す前に必ずショートチェックを実施してください。 
  

ケースに入れる場合Y1を少し曲げて、ケースに当たらない様にしてください。   

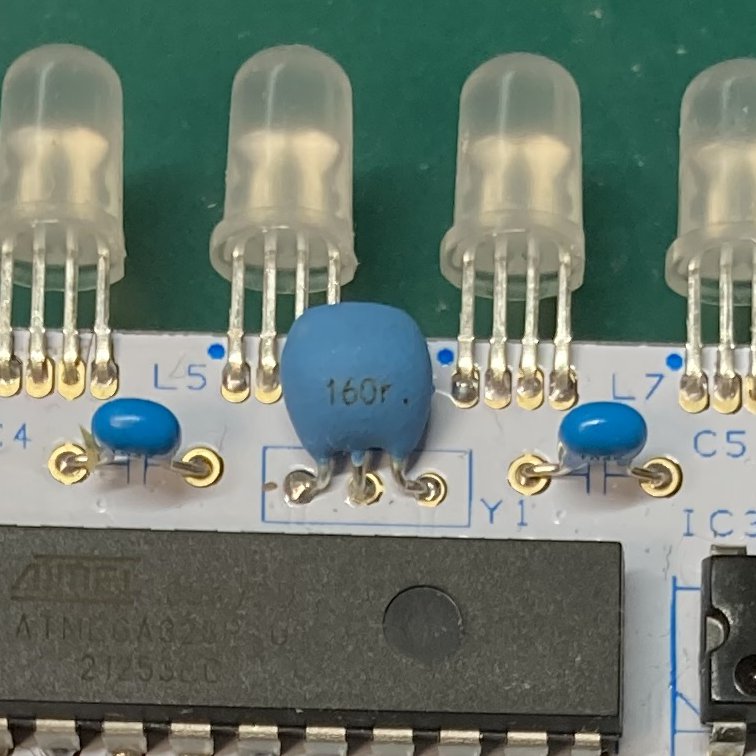
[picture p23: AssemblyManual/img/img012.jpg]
  

## ショートチェック

実機に挿す前にショートが無いか良く確認してください。  
テスタを持っているのであれば、写真の位置でVCC-GNDおよびLED電源のショートチェックを行ってください。  
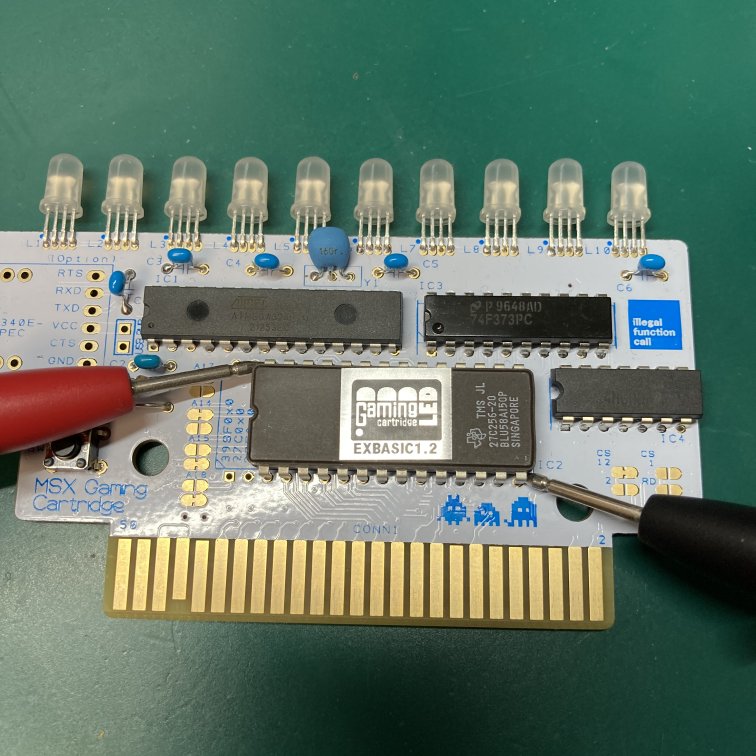
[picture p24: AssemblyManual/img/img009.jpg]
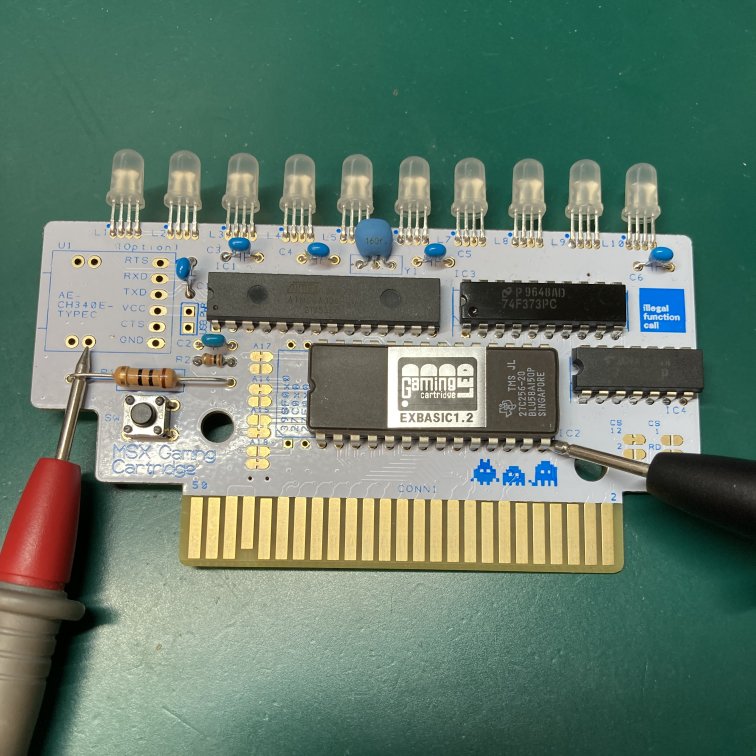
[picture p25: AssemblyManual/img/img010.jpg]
 

## Arduinoスケッチの書き込み (基板＋EPROM版 購入者のみ）

USBシリアルを接続後、MSXに挿入してCartridgeに電源を入れてください。  
(AE-CH340Eを使わない場合はRXD/TXDを接続してください)  

スロットの形状によっては、ケーブルを接続したままで挿入出来ない場合があります。  
その場合は、近傍にあるUSB PWRのジャンパをショートさせUSBから電源供給をしてください。  
（5VがMSXに流れ込むので、書き込み後はオープンに戻してください）

Arduinoのインストールや細かい使い方はここでは割愛します。  
ボード選択はArduino UNO、COMポートはUSBシリアルの番号を選択してください。  
「マイコンボードに書き込む」のアイコンをクリックし、プログラムの書き込みを完了してください。  
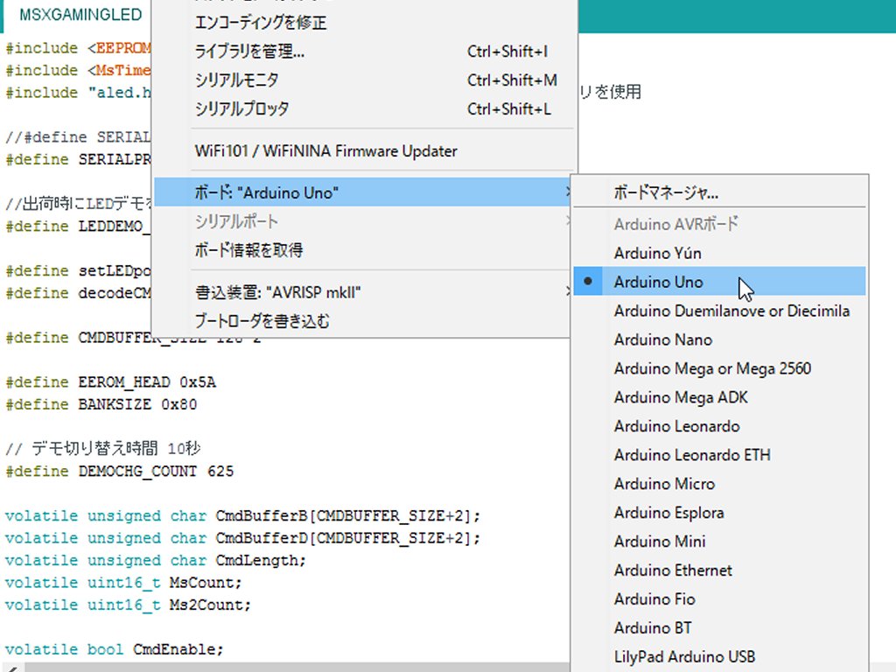
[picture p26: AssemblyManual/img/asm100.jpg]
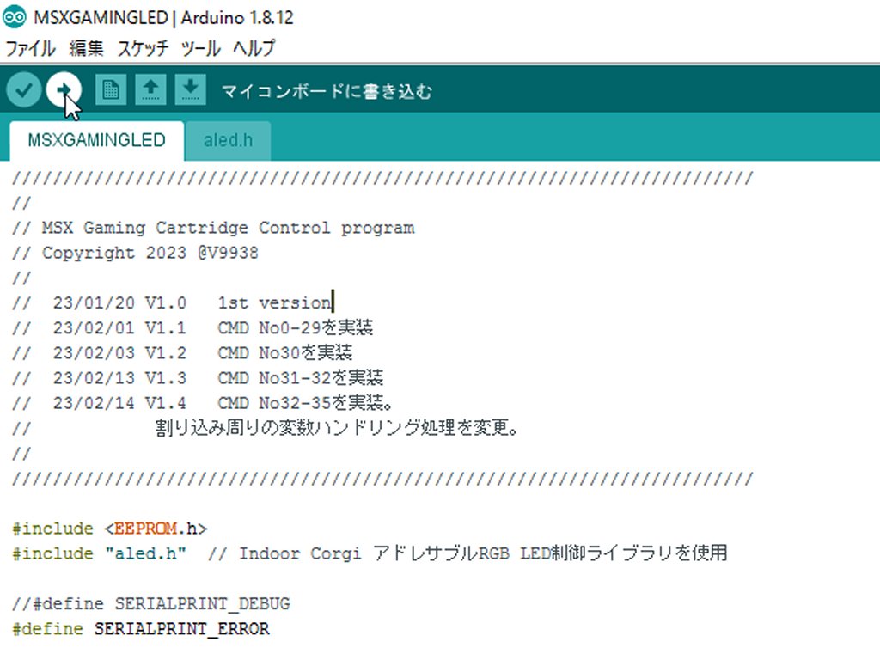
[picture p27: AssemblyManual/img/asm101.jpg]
  

## 動作チェック  

出荷状態であれば、電源を入れると自動的にLEDのデモパターン0～4が実行されます。  

### LEDが光らない/一部が光らない場合

大抵はLED部の半田付け不良です。R1が熱くなる場合は、L1-10のいずれかがショートしています。  
特に、LED部の4つのパッドの真ん中2つがショートしやすいです。そこを確認してみてください。  
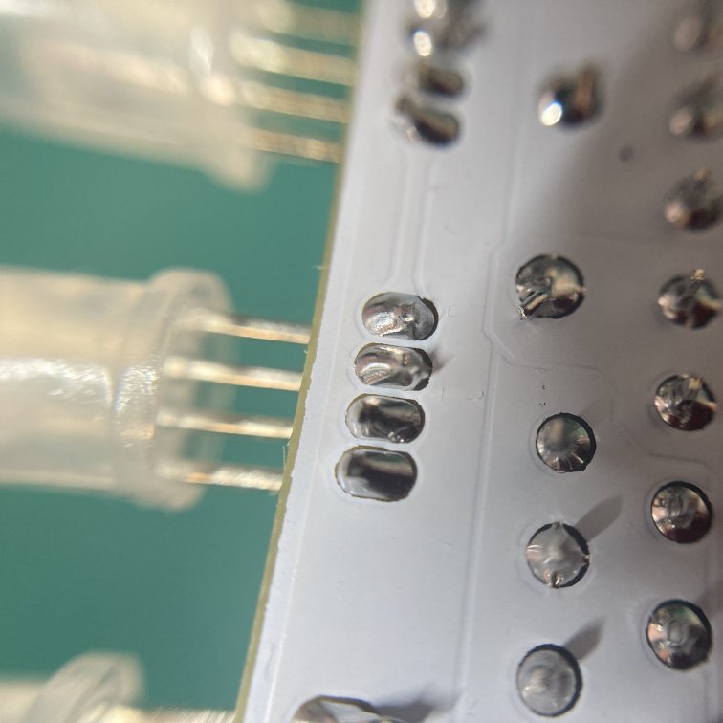
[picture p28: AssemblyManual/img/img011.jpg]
 

### MSX本体が起動しない場合

IC2/IC3/IC4のいずれかの実装不良の可能性があります。

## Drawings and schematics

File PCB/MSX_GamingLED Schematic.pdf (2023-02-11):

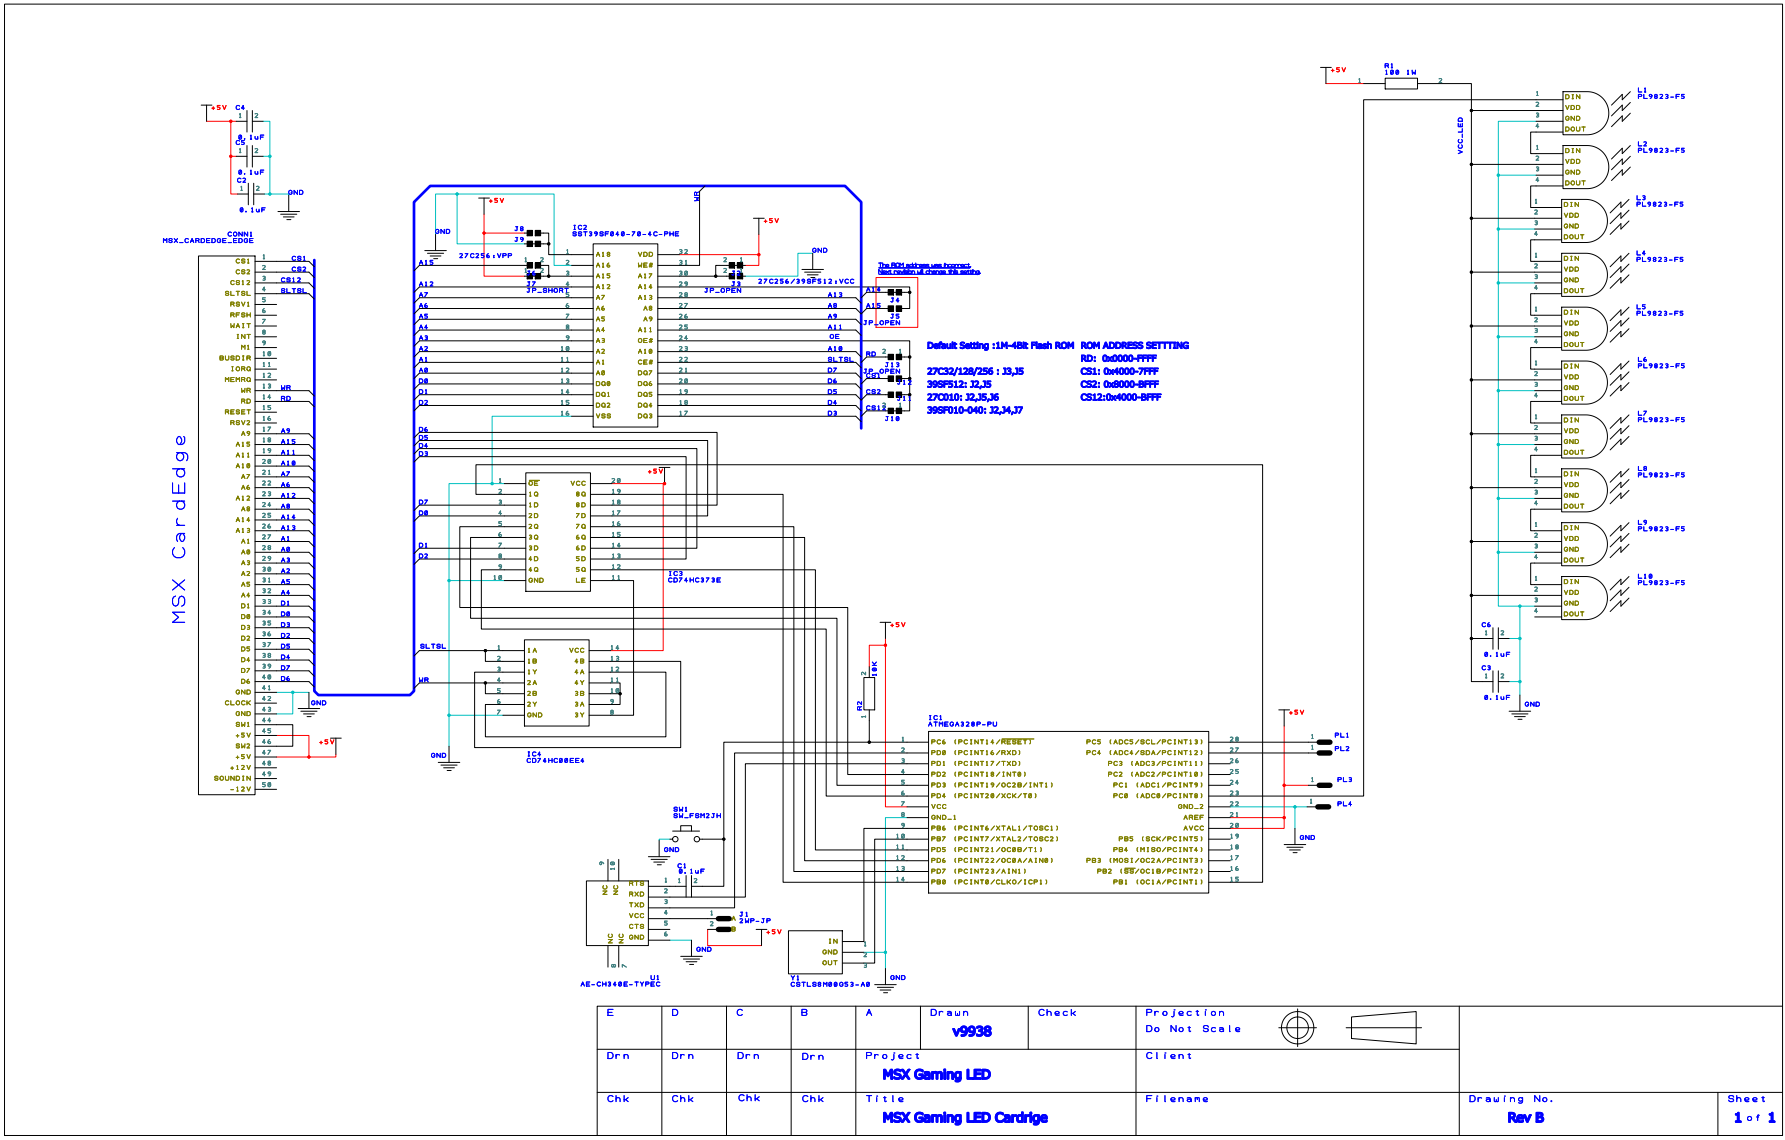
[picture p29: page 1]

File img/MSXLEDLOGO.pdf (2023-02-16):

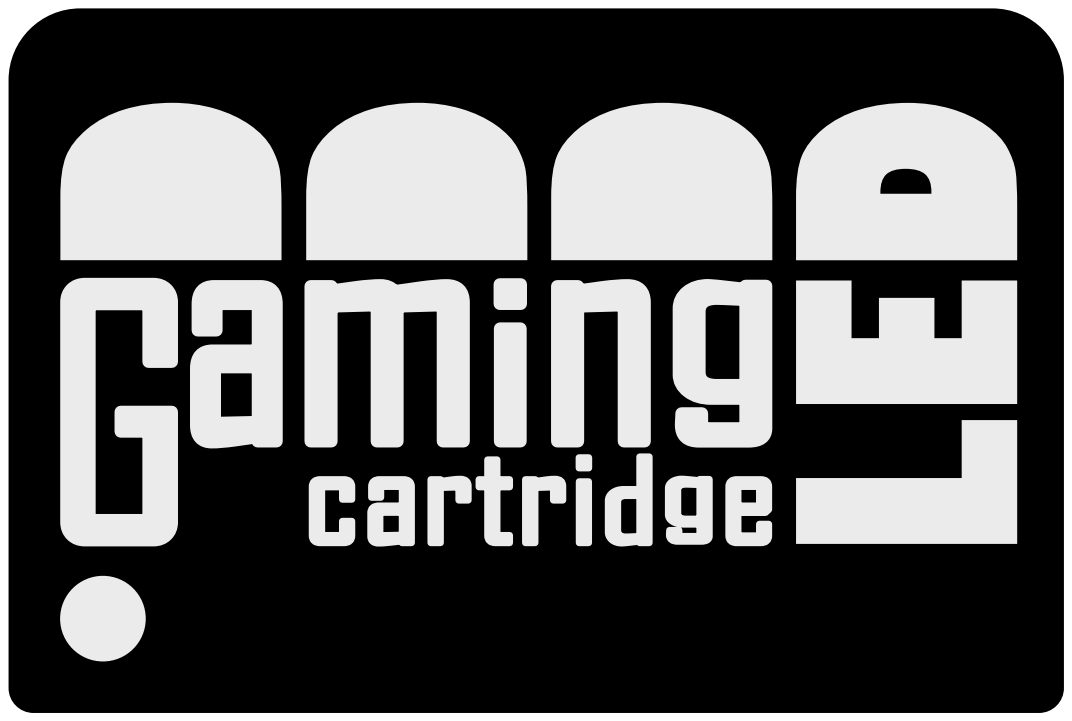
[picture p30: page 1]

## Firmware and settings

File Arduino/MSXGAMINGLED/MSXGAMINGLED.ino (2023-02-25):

////////////////////////////////////////////////////////////////////////
//
// MSX Gaming Cartridge Control program
// Copyright 2023 @V9938
//	
//	23/01/20 V1.0		1st version
//	23/02/01 V1.1		CMD No0-29を実装
//	23/02/03 V1.2		CMD No30を実装
//	23/02/13 V1.3		CMD No31-32を実装
//	23/02/14 V1.4		CMD No32-35を実装。
//						割り込み周りの変数ハンドリング処理を変更。
//	23/02/20 V1.5		LEDAの演算処理の計算式が誤っていたので修正
//
////////////////////////////////////////////////////////////////////////

#include <EEPROM.h>
#include "aled.h"  // Indoor Corgi アドレサブルRGB LED制御ライブラリを使用

//#define SERIALPRINT_DEBUG
//#define SERIALPRINT_ERROR

//出荷時にLEDデモを有効にするか
#define LEDDEMO_DEF_ENABLE

//時間計測用のCMD IN/OUT有効化
//#define CMDINOUT_ENABLE

#define setLEDpos(x) aled.pos = 5.0f + (float) x * 10.0f
#define decodeCMD(i) 0xff & (((unsigned char)(CmdBufferD[i] >> 2)) | (CmdBufferB[i] << 6))

#define errorLedOn		digitalWrite(16,HIGH)
#define errorLedOff		digitalWrite(16,LOW)

#ifdef CMDINOUT_ENABLE
#define cmdLedIn		digitalWrite(15,HIGH)
#define cmdLedOut		digitalWrite(15,LOW)
#else
#define cmdLedIn 
#define cmdLedOut 
#endif


#define CMDBUFFER_SIZE 128*2

#define EEROM_HEAD 0x5A
#define BANKSIZE 0x80

// デモ切り替え時間 10秒
#define DEMOCHG_COUNT 625

//ERROR LED点灯時間 2秒
#define ERRORLED_COUNT 125

volatile unsigned char CmdBufferB[CMDBUFFER_SIZE+2];
volatile unsigned char CmdBufferD[CMDBUFFER_SIZE+2];
volatile unsigned char CmdLength;
volatile uint16_t MsCount;
volatile uint16_t Ms2Count;


volatile bool CmdEnable;
unsigned char CmdHead;
unsigned char CurrentCmdHead;

unsigned char CmdOption;
unsigned char CmdStatus;
unsigned char Cmd;

uint16_t TimeOutMs;
uint16_t ErrorMS;
bool timeOutEnable;

uint16_t ChangeMs;
uint16_t ErrorMs;
uint16_t DemoChangeTime;
unsigned char DemoStartBank;
unsigned char DemoEndBank;

bool DebugOut;
bool LedDemoAll;

uint16_t DemoPattern;
uint16_t DemoCountMs;

bool ChangeEnable;
bool ChangeHueMode;
bool ChangeSatMode;
bool ChangeValMode;
bool ChangePosMode;

bool ResetCmdLength;
bool ResetMsCount;

float ChangeHueMode_sign;
float  ChangeSatMode_sign;
float ChangeValMode_sign;
float ChangePosMode_sign;

//一次保存用ワーク
float pushHue,pushSat,pushVal,pushPos;
uint8_t pushPattern;

// Time Out = 16x6=96ms
#define CMD_TIMEOUT     6

#define WAIT_STARTCMD   0
#define WAIT_CMD        1
#define WAIT_CMDOPTION  2


// COMMAND TABLE

#define MAX_CMD 36

#define cl_debugen  0  // (2Byte) Debug Message
#define cl_off      1  // (1Byte) LED OFF/DEMO STOP  No1
#define cl_draw     2  // (1Byte) LED draw       No2
#define cl_pos      3  // (2Byte) LED position setting No3

#define cl_pat      4  // (2Byte) LED pattern setting  No4
#define cl_eepinit  5  // (1Byte) EEPROM 初期化        No5
#define cl_demo     6  // (4Byte) LED DEMO       No6
#define cl_real     7  // (9Byte) No7 未使用　倍精度テスト用

#define cl_c_rgb    8  // (4Byte) RGB Coler code   No8
#define cl_c_hue    9  // (9Byte) HSV Coler code hue   No9
#define cl_c_sat    10  // (9Byte) HSV Coler code sat   No10
#define cl_c_val    11  // (9Byte) HSV Coler code val   No11

#define cl_p_hue    12  // (9Byte) Gradation Pattern hue step value   No12
#define cl_p_rep    13  // (2Byte) LED pattern repeat value     No13
#define cl_a_enable 14  // (1Byte) LED Animation enable No14
#define cl_a_dis    15  // (1Byte) LED Animation disable No15

#define cl_a_hue    16  // (9Byte) HSV Animation hue    No16
#define cl_a_sat    17  // (9Byte) HSV Animation sat    No17
#define cl_a_val    18  // (9Byte) HSV Animation val    No18
#define cl_a_pos    19  // (9Byte) HSV Animation pos    No19

#define cl_a_modeh  20  // (2Byte) HSV AnimationMode hue   No20
#define cl_a_modes  21  // (2Byte) HSV AnimationMode sat   No21
#define cl_a_modev  22  // (2Byte) HSV AnimationMode val   No22
#define cl_a_modep  23  // (2Byte) HSV AnimationMode pos   No23

#define cl_p_sat	24	// (9Byte) Gradation Pattern sat step value   No24
#define cl_p_val	25	// (9Byte) Gradation Pattern val step value   No25
#define cl_p_aval	26	// (9Byte) Gradation Pattern all val value    No26
#define cl_ee_set   27  // (2Byte) EEPROM Write

#define cl_ee_get   28  // (2Byte) EEPROM Read 
#define cl_ee_cnf   29  // (1Byte) EEPROM Config set
#define cl_a_pause  30  // (2Byte) AnimationMode pause
#define cl_p_rgb    31  // (5Byte) Color Parameter set (RGB format)

#define cl_p_hsv    32  // (6Byte) Color Parameter set (HSV format)
#define cl_null     33  // (1Byte) NULL CMD (Start CMDと共通なのでNULLにしている） No33
#define cl_p_rgball 34  // (31Byte) ALL Color Parameter set & Draw(RGB) No34
#define cl_p_hsvall 35  // (41Byte)  ALL Color Parameter set & Draw(HSV) No35

//Command長テーブル
const unsigned char OptLength[MAX_CMD] = {	0x01,0x00,0x00,0x01, 0x01,0x00,0x03,0x08, 0x03,0x08,0x08,0x08, 
0x08,0x01,0x00,0x00, 0x08,0x08,0x08,0x08, 0x01,0x01,0x01,0x01, 0x08,0x08,0x08,0x01, 0x01,0x00,0x01,0x04, 0x05,0x00,0x1E,0x28};

// アドレサブルRGB制御用のALEDクラスを使う
//  デフォルトは全チャネルに同じデータを送信
//  LED数は使うデバイスに合わせる
ALED aled(CH1, 10,0,0,0,0);

void rgb2hsv(uint8_t red,uint8_t green,uint8_t blue){
	uint8_t max_rgb,min_rgb;

	max_rgb = red;
	if (max_rgb < green) max_rgb = green;
	if (max_rgb < blue) max_rgb = blue; // RGBの中の最大値

	min_rgb = red;
	if (min_rgb > green) min_rgb = green;
	if (min_rgb > blue) min_rgb = blue;

	aled.color.val = ((float)max_rgb/255.0f)*100.0f;

	if (max_rgb != 0.0)  aled.color.sat = ((float)(max_rgb-min_rgb)/(float)max_rgb)*100.0f;
	else aled.color.sat = 0.0f;

	if ((red == green) && (red == blue))aled.color.hue = 0.0f;
	else {
		if (max_rgb == 0)           aled.color.hue = 0.0f;
		else if (max_rgb == red)    aled.color.hue = ((float)(green - blue) / (float)(max_rgb - min_rgb)) * 60.0f;
		else if (max_rgb == green)  aled.color.hue = (2.0f + (float)(blue - red) / (float)(max_rgb - min_rgb)) * 60.0f;
		else                        aled.color.hue = (4.0f + (float)(red - green) / (float)(max_rgb - min_rgb)) * 60.0f;
	}

}
void clearCmd(){
	if (CmdLength == CmdHead)  {

//		noInterrupts();
//		CmdHead = 0;
//		CmdLength = 0;    // CMDバッファーリセット
//		interrupts();

		CmdHead = 0;
		ResetCmdLength = true;		//Lengthリセット要求
	}
	timeOutEnable = false;
	CmdStatus = WAIT_STARTCMD ;
}
void setup() {
// 使うピンを出力に設定
	pinMode(16, OUTPUT);  // Debug port
	pinMode(15, OUTPUT);  // Debug port
	pinMode(14, OUTPUT);  // チャネル1 Pin14, PC0
	pinMode(2, INPUT);   // DAT0
	pinMode(3, INPUT);   // DAT1
	pinMode(4, INPUT);   // DAT2
	pinMode(5, INPUT);   // DAT3
	pinMode(6, INPUT);   // DAT4
	pinMode(7, INPUT);   // DAT5
	pinMode(8, INPUT);   // DAT6
	pinMode(9, INPUT);   // DAT7

	digitalWrite(16,LOW);
	digitalWrite(15,LOW);


//割り込み設定
	EICRA |= (3 << ISC00);    // Trigger on pos edge
	EIMSK |= (1 << INT0);     // Enable external interrupt INT0 = pin3

	TCCR2A = 0;           
	TCCR2B = 0;          
	TCCR2A |= (1 << WGM21);   						//CTC mode
	TCCR2B |= (1 << CS22)|(1 << CS21|(1 << CS20));  //分周1024
	OCR2A   = 250-1;         						//250カウント=16ms
	TIMSK2 |= (1 << OCIE2A);						//TIMER2割り込み有効

	CmdLength = 0;    // CMDバッファーの長さ
	MsCount = 0;      // 1msカウンター（CMD TimeOut管理用）
	CmdHead = 0;
	CmdStatus = WAIT_STARTCMD ;
	timeOutEnable =false;
	ResetCmdLength = true;
	ResetMsCount = true;
	
//attachInterrupt(digitalPinToInterrupt(2),setcmd_func,RISING);

//	MsTimer2::set(16, ms_counter); // 16msカウント
//	MsTimer2::start();




//	sei();                    // Enable global interrupts




// initialize serial and wait for port to open:
	Serial.begin(115200);
//  while (!Serial) {
//    ; // wait for serial port to connect. Needed for native USB port only
//  }
	Serial.println("MSX Gaming LED System");
	Serial.println("firmware rev 1.5(02/20/2023) @v9938");

//LED消灯
	aled.reset(true);

// Temp Buffer初期化
	pushHue = 360.0f;
	pushSat = 100.0f;
	pushVal = 0.0f;
	pushPos = 0.0f;

	noInterrupts();

// アニメーションパターン系初期値
	ChangeMs = 0; 			//更新カウンター
	DemoCountMs = 0;
	DemoPattern = 0;

	setInitParameter();				//初期値設定


	eeprom_get();			//EEPROMの設定値で上書き


	interrupts();
// DEMOモードが有効の場合は値を更新
	if (ChangeEnable) {
		Serial.println("Demo Mode ON");
		setDemoValue(DemoStartBank);
		aled.draw();
	}


	#ifdef SERIALPRINT_ERROR
	if (DebugOut)	Serial.println("User Debug mode ON");
	#endif
	#ifdef SERIALPRINT_DEBUG
	Serial.println("All print mode ON");
	#endif

	Serial.println();


}

void __INT0_vect(){};		//エディタの都合のDummy関数
ISR(INT0_vect)//pin3
{
	if (ResetCmdLength) {
		CmdLength = 0;
		ResetCmdLength = false;
	}
	
	CmdBufferB[CmdLength] = PINB;
	CmdBufferD[CmdLength] = PIND;
	CmdLength++;
}

void __TIMER2_COMPA_vect(){};		//エディタの都合のDummy関数
ISR (TIMER2_COMPA_vect)
//void ms_counter(){
{
	interrupts();     //INT0割り込みは最優先なので有効にしておく
	if (ResetMsCount) {
		MsCount = 0;
		ResetMsCount = false;
	}else{
		MsCount++;
	}
	Ms2Count++;
}
uint16_t marge16bit(uint16_t pos) {
	uint16_t upper,lower;
	uint16_t value;

	upper = 0x7f & ((uint16_t)(decodeCMD(pos+1))>>1);
	lower = 0x7f & ((uint16_t)(decodeCMD(pos+0))>>1);
	value = (upper << 7) | lower;

	return value;

}
float fpow(uint16_t n)
{
	uint16_t i;
	float ret = 1.0;

	for (i = 0; i < n; i++) {
		ret *= 10;
	}

	return ret;
}

//2進化10進数から10進数
float BCDtoDEC(unsigned char* Pointer){
	char bu[10];
	uint8_t b,c,d,e,f,g;
	float dec;
	int8_t s;

	dec = 0.0f;
	b = (*(Pointer+1))>>4;
	c = (*(Pointer+1))&0x0f;
	d = (*(Pointer+2))>>4;
	e = (*(Pointer+2))&0x0f;
	f = (*(Pointer+3))>>4;
	g = (*(Pointer+3))&0x0f;

	dec = (float)b * 100000.0f + (float)c * 10000.0f + (float)d * 1000.0f + (float)e *100.0f + (float)f *10.0f +(float)g;
	#ifdef SERIALPRINT_DEBUG
	Serial.print("\nBCD :  ");
	Serial.println(dec,6);
	#endif
	dec = pow(10.0f,((float)(*(Pointer) & 0x7f)-70.0f))*dec;
	if ((*(Pointer) & 0x80) == 0x80) dec = dec * -1.0f; 
	return dec;
}
float getFloat(){
	unsigned char bcd[4];
	float num;

	bcd[0]=(unsigned char) marge16bit(CmdOption+0);
	bcd[1]=(unsigned char) marge16bit(CmdOption+2);
	bcd[2]=(unsigned char) marge16bit(CmdOption+4);
	bcd[3]=(unsigned char) marge16bit(CmdOption+6);
	num =BCDtoDEC(bcd);

	#ifdef SERIALPRINT_DEBUG
	Serial.print("\ngetFloat :  ");
	Serial.println(num,6);
	#endif

	return num;
}

float getFloat360(){
	float temp;

	temp = getFloat();
//丸め誤差対策
	if (temp >= 360.0f) temp = 360.0f;
	if (temp <= -360.0f) temp = -360.0f;
	return temp;
}
float getFloat100(){
	float temp;

	temp = getFloat();
//丸め誤差対策
	if (temp >= 100.0f) temp = 100.0f;
	if (temp <= -100.0f) temp = -100.0f;
	return temp;
}
void eeprom_setData(int Address){
	int eeAddress = Address;   // 書き込むデータの最初のアドレス


	EEPROM.put(eeAddress, aled.pos);
	eeAddress += sizeof(aled.pos);

	EEPROM.put(eeAddress, aled.repeat);
	eeAddress += sizeof(aled.repeat);

	EEPROM.put(eeAddress, aled.color.hue);
	eeAddress += sizeof(aled.color.hue);

	EEPROM.put(eeAddress, aled.color.sat );
	eeAddress += sizeof(aled.color.sat );

	EEPROM.put(eeAddress, aled.color.val);
	eeAddress += sizeof(aled.color.val);

	EEPROM.put(eeAddress, aled.colorPattern.hue);
	eeAddress += sizeof(aled.colorPattern.hue);

	EEPROM.put(eeAddress, aled.colorPattern.sat );
	eeAddress += sizeof(aled.colorPattern.sat );

	EEPROM.put(eeAddress, aled.colorPattern.val);
	eeAddress += sizeof(aled.colorPattern.val);

	EEPROM.put(eeAddress, ChangeHueMode);
	eeAddress += sizeof(ChangeHueMode);

	EEPROM.put(eeAddress, ChangeSatMode);
	eeAddress += sizeof(ChangeSatMode);

	EEPROM.put(eeAddress, ChangeValMode);
	eeAddress += sizeof(ChangeValMode);

	EEPROM.put(eeAddress, ChangePosMode);
	eeAddress += sizeof(ChangePosMode);


	EEPROM.put(eeAddress, aled.colorChange.hue);
	eeAddress += sizeof(aled.colorChange.hue);

	EEPROM.put(eeAddress, aled.colorChange.sat);
	eeAddress += sizeof(aled.colorChange.sat);

	EEPROM.put(eeAddress, aled.colorChange.val);
	eeAddress += sizeof(aled.colorChange.val);

	EEPROM.put(eeAddress, aled.posChange);
	eeAddress += sizeof(aled.posChange);

	EEPROM.put(eeAddress, aled.pattern);
	eeAddress += sizeof(aled.pattern);

}
void eeprom_setCommon(){
	int eeAddress = 0x10;

	eeAddress += sizeof(DebugOut);

	EEPROM.put(eeAddress, ChangeEnable);
	eeAddress += sizeof(ChangeEnable);
	EEPROM.put(eeAddress, LedDemoAll);
	eeAddress += sizeof(LedDemoAll);
	EEPROM.put(eeAddress, DemoChangeTime);
	eeAddress += sizeof(DemoChangeTime);
	EEPROM.put(eeAddress, DemoStartBank);
	eeAddress += sizeof(DemoStartBank);
	EEPROM.put(eeAddress, DemoEndBank);
	eeAddress += sizeof(DemoEndBank);
	EEPROM.put(eeAddress, DebugOut);
	eeAddress += sizeof(DebugOut);


}
void eeprom_init(){
	int eeAddress = 0x10;

	Serial.println("EEPROM INIT...");

	EEPROM.write(0,EEROM_HEAD);		//HEADER

	EEPROM.put(eeAddress, DebugOut);
	eeAddress += sizeof(DebugOut);

	EEPROM.put(eeAddress, ChangeEnable);
	eeAddress += sizeof(ChangeEnable);
	EEPROM.put(eeAddress, LedDemoAll);
	eeAddress += sizeof(LedDemoAll);
	EEPROM.put(eeAddress, DemoChangeTime);
	eeAddress += sizeof(DemoChangeTime);
	EEPROM.put(eeAddress, DemoStartBank);
	eeAddress += sizeof(DemoStartBank);
	EEPROM.put(eeAddress, DemoEndBank);
	eeAddress += sizeof(DemoEndBank);



	eeprom_setData(BANKSIZE+BANKSIZE*0);	//BANK0
	eeprom_setData(BANKSIZE+BANKSIZE*1);	//BANK1
	eeprom_setData(BANKSIZE+BANKSIZE*2);	//BANK2
	eeprom_setData(BANKSIZE+BANKSIZE*3);	//BANK3
	eeprom_setData(BANKSIZE+BANKSIZE*4);	//BANK4

}

void eeprom_getData(int Address){
	int eeAddress = Address;   // 書き込むデータの最初のアドレス

	EEPROM.get(eeAddress, aled.pos);
	eeAddress += sizeof(aled.pos);

	EEPROM.get(eeAddress, aled.repeat);
	eeAddress += sizeof(aled.repeat);

	EEPROM.get(eeAddress, aled.color.hue);
	eeAddress += sizeof(aled.color.hue);

	EEPROM.get(eeAddress, aled.color.sat );
	eeAddress += sizeof(aled.color.sat );

	EEPROM.get(eeAddress, aled.color.val);
	eeAddress += sizeof(aled.color.val);

	EEPROM.get(eeAddress, aled.colorPattern.hue);
	eeAddress += sizeof(aled.colorPattern.hue);

	EEPROM.get(eeAddress, aled.colorPattern.sat );
	eeAddress += sizeof(aled.colorPattern.sat );

	EEPROM.get(eeAddress, aled.colorPattern.val);
	eeAddress += sizeof(aled.colorPattern.val);


	EEPROM.get(eeAddress, ChangeHueMode);
	eeAddress += sizeof(ChangeHueMode);

	EEPROM.get(eeAddress, ChangeSatMode);
	eeAddress += sizeof(ChangeSatMode);

	EEPROM.get(eeAddress, ChangeValMode);
	eeAddress += sizeof(ChangeValMode);

	EEPROM.get(eeAddress, ChangePosMode);
	eeAddress += sizeof(ChangePosMode);


	EEPROM.get(eeAddress, aled.colorChange.hue);
	eeAddress += sizeof(aled.colorChange.hue);

	EEPROM.get(eeAddress, aled.colorChange.sat);
	eeAddress += sizeof(aled.colorChange.sat);

	EEPROM.get(eeAddress, aled.colorChange.val);
	eeAddress += sizeof(aled.colorChange.val);

	EEPROM.get(eeAddress, aled.posChange);
	eeAddress += sizeof(aled.posChange);

	EEPROM.get(eeAddress, aled.pattern);
	eeAddress += sizeof(aled.pattern);



}

void eeprom_get(){

	int eeAddress = 0x10;

//Header Check
	if (EEPROM.read(0) != EEROM_HEAD) eeprom_init();

	EEPROM.get(eeAddress, DebugOut);
	eeAddress += sizeof(DebugOut);

	EEPROM.get(eeAddress, ChangeEnable);
	eeAddress += sizeof(ChangeEnable);
	EEPROM.get(eeAddress, LedDemoAll);
	eeAddress += sizeof(LedDemoAll);
	EEPROM.get(eeAddress, DemoChangeTime);
	eeAddress += sizeof(DemoChangeTime);
	EEPROM.get(eeAddress, DemoStartBank);
	eeAddress += sizeof(DemoStartBank);
	EEPROM.get(eeAddress, DemoEndBank);
	eeAddress += sizeof(DemoEndBank);

//電源ON時の設定値をロード
	eeprom_getData(BANKSIZE+BANKSIZE*DemoStartBank);			//BANK0 Dataは56Byte
}

void setInitParaAnimation(){
	ChangeEnable = false;		//アニメーションOFF
	LedDemoAll = false;


//アニメーションパターンの設定
//true = 往復 / false=片道
	ChangeHueMode	= false;
	ChangeSatMode	= false;
	ChangeValMode	= false;
	ChangePosMode	= false;

//往復モード時の方向フラグ disable時に戻すこと
	ChangeHueMode_sign	= 1.0f;
	ChangeSatMode_sign	= 1.0f;
	ChangeValMode_sign	= 1.0f;
	ChangePosMode_sign	= 1.0f;

	aled.colorChange.hue = 1.0f;
	aled.colorChange.sat = 0.0f;
	aled.colorChange.val = 0.01f;
	aled.posChange = 1.00f;

#ifdef LEDDEMO_DEF_ENABLE
	ChangeEnable = true;		//アニメーションOFF
	LedDemoAll = true;
#endif

}
void setInitParaDemo(){
// Demo系の初期値設定
	DemoChangeTime = DEMOCHG_COUNT;		//DEMO時間初期値
	DemoStartBank = 0;					//DEMO0
	DemoEndBank = 4;					//DEMO4
	DemoPattern = 0;

}

void setInitParameter(){

	DebugOut = false;			//Debug表示は速度を稼ぐ為にOFF
	setInitParaDemo();			//DEMO系Parameter
	setInitParaAnimation();		//LED Animation Parameter

//初期設定値
	aled.pos = 0.0f;			// LED位置0%
	aled.repeat = 1;			// 全色をLED全部

// 表示する模様の基準の色を指定する
// 今回の例では基準の色は以下の値から変更しない
	aled.color.hue = 0.0f;
	aled.color.sat = 100.0f;
	aled.color.val = 100.0f;

// グラデーション模様の色の変化量を指定する
// 今回の例では以下の虹色模様から変更しない
	aled.colorPattern.hue = 360.0f;
	aled.colorPattern.sat = 0.0f;
	aled.colorPattern.val = 0.0f;

// アニメーションパターン系初期値
	aled.pattern = ALED::patGrad;  // 色相グラデーションパターン1 (100%パターン)
}

void setDemoValue(uint16_t value){

//DEMO番号5～はUSER patternなのでeepromから取得して終わり
	if (value > 4){
		eeprom_getData(BANKSIZE+BANKSIZE*(value-5));			//BANK0 Dataは56Byte
		return;
	}
	
//以下プリセットpattern生成

// グラデーション模様の色の変化量を指定する
// 今回の例では以下の虹色模様から変更しない
	aled.colorPattern.hue = 360.0f;
	aled.colorPattern.sat = 0.0f;
	aled.colorPattern.val = 0.0f;


//アニメーションパターンの設定
//true = 往復 / false=片道
	ChangeHueMode	= false;
	ChangeSatMode	= false;
	ChangeValMode	= true;
	ChangePosMode	= false;

//往復モード時の方向フラグ 必要に応じて戻すこと
//		  ChangeHueMode_sign	= 1.0f;
//		  ChangeSatMode_sign	= 1.0f;
//		  ChangeValMode_sign	= 1.0f;
//		  ChangePosMode_sign	= 1.0f;


//16ms毎の値の変化量設定
	aled.colorChange.hue = 1.0f;
	aled.colorChange.sat = 0.0f;
	aled.colorChange.val = 0.5f;
	aled.posChange = 1.00f;
	aled.pattern = (uint8_t) value;
	
//patternだけ同じだと面白く無いので少し弄る
	if (value == ALED::patSingle) {		// 全体フラッシュ
		aled.colorChange.val = 1.00f;
	}

	if (value == ALED::patGrad) {		// 色相グラデーションパターン1 (100%パターン)
		aled.posChange = 5.00f;
	}

	if (value == ALED::patSym) {		// 色相グラデーションパターン2 (50%パターン)
		aled.posChange = 0.80f;
	}
	if (value == ALED::patPoint1) {		// LED1灯のみ光らせるパターン(他は消灯)
		aled.posChange = 0.50f;
		ChangePosMode	= true;
	}
	if (value == ALED::patPoint2) {		// LED1灯のみデータ更新するパターン(他は前の状態を維持)
		aled.posChange = 2.00f;
		ChangePosMode	= true;
	}
}

void debugDoCMD_InParameter(){

	unsigned char bcd[4];
	char buf[100];
	unsigned char* ddd;
    float ppp;
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
void loop() {
	char buf[60];
	uint16_t tmpMsCount;

	interrupts();													//割り込み許可

// CMD関係の処理
	if ((ResetCmdLength==false) && (CmdLength != CmdHead)){				// CMD入力有り
		timeOutEnable = true;											// TimeOutフラグを有効化
		CurrentCmdHead = CmdHead;										// 今のHead位置を移す
		CmdHead++;														// 次のSearch位置を更新
		tmpMsCount = MsCount;											// TimeOut計測用カウンター値取得
		if ((tmpMsCount + CMD_TIMEOUT) <  TimeOutMs){					// TimeOut値の計算結果が0戻りの場合の対策
			 ResetMsCount = true;										// 次の割り込みでカウンターを初期化
		}else{
			TimeOutMs = MsCount + CMD_TIMEOUT;							// TimeOut値を設定
		}

		//CmdStatus: WAIT_STARTCMD(MagicWord待ち)
		if (CmdStatus == WAIT_STARTCMD){
			// Start CMDが来た時の処理
			if ((decodeCMD(CurrentCmdHead))== 0x43)  {					// StartCMD:0x43
				CmdStatus = WAIT_CMD ;								// 次のステータスへ
			}else{
			// Start CMD以外の書き込みがあった場合の処理（BIOSのRAM Searchとかで普通にある）
#ifdef SERIALPRINT_DEBUG
				sprintf(buf, "WAIT_STARTCMD Unknow: 0x%02x L: %d H: %d to: %d t:%d", (decodeCMD(CurrentCmdHead)),CmdLength,CmdHead,TimeOutMs,MsCount);
				Serial.println(buf);
#endif
				ErrorMS = 1;															// 
				clearCmd();																// 現在のCMDをclear
			}
		}else if (CmdStatus == WAIT_CMD){
			//CmdStatus: WAIT_CMD(CMD書き込み待ち)

			if (((decodeCMD(CurrentCmdHead))>>1) < MAX_CMD)  {								//CMDが有効範囲かチェック

				Cmd = (decodeCMD(CurrentCmdHead));
				Cmd = (Cmd >>1) ;              											//CMD番号
				CmdOption = CmdHead;    												//CMD オプションのスタート位置
				CmdStatus = WAIT_CMDOPTION ;											//CMD OPTION待ちステータス
#ifdef SERIALPRINT_DEBUG
				sprintf(buf, "WAIT_CMD CMD: 0x%02x L: %d H: %d", Cmd,CmdLength,CmdHead);
				Serial.println(buf);
#endif
				if(OptLength[Cmd] == 0) {												//Option無しのCMDの場合即時実行
					doCMD();
				}
			}else{
				// 範囲外の無効コマンドが来た場合
#ifdef SERIALPRINT_ERROR
				if (DebugOut){
					sprintf(buf, "WAIT_CMD Unknow: 0x%02x L: %d H: %d to: %d t:%d", (decodeCMD(CurrentCmdHead)),CmdLength,CmdHead,TimeOutMs,MsCount);
					Serial.println(buf);
				}
#endif
				ErrorMS = 1;
				clearCmd();									//無効コマンド
			}
		}else if (CmdStatus == WAIT_CMDOPTION){
			//CmdStatus: WAIT_CMDOPTION(CMDの引数が来るのを待つ)
			if ((CmdOption+OptLength[Cmd]) == CmdHead) {	//CMD長まで来たら有効化

				doCMD();									//CMD実行
			}
		}else{
			//CmdStatus: その他　（通常は絶対踏まない)
#ifdef SERIALPRINT_ERROR
			if (DebugOut){
				Serial.println("Invaild Status");
			}
#endif
			ErrorMS = 1;
			clearCmd();									//無効コマンド
		}
	}

	// BufferのOverflow検出処理
	// UART処理で時間がかからない限り通常ここは通らない。
	if (CmdHead == CMDBUFFER_SIZE-1){
		#ifdef SERIALPRINT_ERROR
		if (DebugOut){
			Serial.println("CMD Buffer Over");
		}
		#endif

		ErrorMS = 1;
		clearCmd();
	}
	//TimeOut処理

	if ((ResetMsCount==false)&&(timeOutEnable == true)&&(TimeOutMs < MsCount)){
		//CMD Time Out 96ms
#ifdef SERIALPRINT_ERROR
		if(DebugOut){
			Serial.println("CMD Time out");
		}
#endif
		ErrorMS = 1;
		clearCmd();
	}

//16ms単位でやる処理(MsCountはTime Out処理で初期化される場合があるのでMs2Countを参照する)
	if (ChangeMs != Ms2Count){					//16msカウンタが更新された時だけ処理を実施

		if (ErrorMS != 0) {						//ErrorLEDの処理 PORT16にLEDを取り付けると見える
			ErrorMS++;
			errorLedOn;
		}
		if (ErrorMS == ERRORLED_COUNT) {
			ErrorMS = 0;
			errorLedOff;
		}
		

		ChangeMs++;								//比較用カウンタ値更新
		if (ChangeEnable){	
			if (LedDemoAll){					//Demopattern切り替え機能が有効の場合
				if (DemoCountMs != DemoChangeTime) DemoCountMs++;			//デモ切り替え時間カウンタを更新
				else {
					// Demo pattern切り替え処理
					DemoCountMs = 0;												//デモ切り替えカウンタ初期化
					if (DemoPattern == DemoEndBank) DemoPattern = DemoStartBank;	//今の設定値が最後だったら戻る
					else DemoPattern++;												//設定値を次に
					setDemoValue(DemoPattern);										//デモ/保存していた設定値に更新
				}
			}

			ledAnimation();						//LEDのアニメーション処理
			if ((ResetCmdLength==true) || (CmdHead== CmdLength)){					//CMDBufferにデータがある場合はそちらの処理を優先する
				aled.draw();													//LED描画中は割り込みが無効でコマンドが受け取れないので注意(800us)
			}
		}
	}

}

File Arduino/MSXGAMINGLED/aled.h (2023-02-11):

//---------------------------------
// CustomARGB用 アドレサブルRGB LEDライブラリ
// Indoor Corgi
// Version 2020/7/4

#include <Arduino.h>
#ifndef ALED_H
#define ALED_H

//---------------------------------
// マクロ

#define CH1 0x1
#define CH2 0x2
#define CH3 0x4
#define CH4 0x8
#define CH5 0x10

// #define DEBUG_PERIOD  // アニメーション描写時間をシリアルモニターに出力。別途Serial.begin()が必要

//---------------------------------
// クラス

// RGB方式で色を管理するクラス
class RGBColor {
 public:
  uint8_t red;
  uint8_t green;
  uint8_t blue;

  // コンストラクタ
  //   指定が無ければ0で初期化
  RGBColor() : red(0), green(0), blue(0) {}

  // コンストラクタ
  //   0 - 255の整数で色を指定
  RGBColor(uint8_t red, uint8_t green, uint8_t blue) : red(red), green(green), blue(blue) {}

  // 0.0 - 100.0の小数で色を指定
  void setFloat(float r, float g, float b) {
    red = (int)(r * 2.55);
    green = (int)(g * 2.55);
    blue = (int)(b * 2.55);
  }
};

// HSV方式で色を管理するクラス
class HSVColor {
 public:
  float hue = 0.0f;  // 色相     0.0 - 360.0
  float sat = 0.0f;  // 色の濃さ 0.0 - 100.0
  float val = 0.0f;  // 明るさ   0.0 - 100.0

  // コンストラクタ
  //   指定が無ければ0で初期化
  HSVColor() : hue(0.0f), sat(0.0f), val(0.0f) {}

  // コンストラクタ
  //   初期値の色を指定
  HSVColor(float hue, float sat, float val) : hue(hue), sat(sat), val(val) {}

  // RGB形式に変換
  RGBColor toRGB() {
    float r = val;
    float g = val;
    float b = val;

    while (hue >= 360.0f) hue -= 360.0f;

    if (sat > 0.0f) {
      float hd = hue / 60.0f;
      int i = (int)hd;
      float f = hd - (float)i;
      switch (i) {
        case 0:
          g *= 1.0f - sat * (1.0f - f) / 100.0f;
          b *= 1.0f - sat / 100.0f;
          break;
        case 1:
          r *= 1.0f - sat * f / 100.0f;
          b *= 1.0f - sat / 100.0f;
          break;
        case 2:
          r *= 1.0f - sat / 100.0f;
          b *= 1.0f - sat * (1.0f - f) / 100.0f;
          break;
        case 3:
          r *= 1.0f - sat / 100.0f;
          g *= 1.0f - sat * f / 100.0f;
          break;
        case 4:
          r *= 1.0f - sat * (1.0f - f) / 100.0f;
          g *= 1.0f - sat / 100.0f;
          break;
        case 5:
          g *= 1.0f - sat / 100.0f;
          b *= 1.0f - sat * f / 100.0f;
          break;
      }
    }

    RGBColor rgb;
    rgb.setFloat(r, g, b);
    return rgb;
  }
};

// アドレサブルRGB LEDを制御し、模様やアニメーションを表示するためのクラス
class ALED {
 public:
  static const uint8_t maxCh = 5;

 protected:
  uint8_t ch;         // 選択チャネル ch1がbit0, ch2がbit1... ch5がbit4に対応
  uint16_t ledCount;  // LEDの数 (物理的な総数ではなく、別々に制御できる数)
  uint32_t lastDrawTime = 0;  // アニメーション周期調整用 最後にdrawした時間を記録
  bool group = false;         // 複数のチャネルをまとめて制御する場合にtrue
  uint16_t ledCounts[maxCh];  // 複数のチャネルをまとめて制御する場合の各デバイスのLEDの数

 public:
  // 模様の種類の切り替え用
  static const uint8_t patSingle = 0;
  static const uint8_t patGrad = 1;
  static const uint8_t patSym = 2;
  static const uint8_t patPoint1 = 3;
  static const uint8_t patPoint2 = 4;
  uint8_t pattern = patGrad;  // 表示する模様の種類

  uint8_t* sendBuf;       // LEDに送信するデータを格納しておくバッファー
  uint16_t* scr;          // 模様の表示する順番を入れ替えるスクランブル情報
  float pos = 0.0f;       // 表示する模様の基準の位置(移動、回転用) 0.0 - 100.0
  HSVColor color;         // 表示する模様の基準の色
  HSVColor colorPattern;  // 表示する模様の場所による色の変化量
  float val = 100.0f;     // 表示する模様の明るさ調整(点滅用) 0.0 - 100.0
  uint8_t repeat = 1;     // 表示する模様の繰り返し回数

  HSVColor colorChange;  // アニメーションの1stepあたり基準の色を変化させる量
  float posChange = 0.0f;  // アニメーションの1stepあたり位置を変化させる量
  float valChange = 0.0f;  // アニメーションの1stepあたり明るさ変化させる量

  // period : アニメーションする際の周期をミリ秒で指定する。
  //   デフォルト33(リフレッシュレート30Hz)
  //   推奨値は25 - 50。低い値のほうがなめらかに見えるが、計算処理が間に合わない場合は
  //     設定値以上の間隔になる。
  uint8_t period = 33;

  // コンストラクタ#1 1つのチャネルを1つのデバイスとして制御する
  //   ch : 出力チャネル
  //     ch1 | ch3 | ch5  とするとチャネル1, 3, 5に同じデータを出力する
  //   ledCount :  制御LEDの数を指定する
  ALED(uint8_t ch, uint16_t ledCount) : ch(ch), ledCount(ledCount) {
    // バッファー初期化
    sendBuf = new uint8_t[ledCount * 3];
    for (uint16_t i = 0; i < ledCount * 3; i++) {
      sendBuf[i] = 0;
    }

    // スクランブル初期化
    scr = new uint16_t[ledCount];
    for (uint16_t i = 0; i < ledCount; i++) {
      scr[i] = i;
    }

    reset();
  }

  // コンストラクタ#2 複数のチャネルをまとめて1つのデバイスのように制御する
  //   ch : 出力チャネル
  //     ch1 | ch3 | ch5  とするとチャネル1, 3, 5をまとめて1つのデバイスのように扱う
  //   ledCountN :  各チャネルの制御LEDの数。選択チャネルが3つの場合は1, 2, 3に指定し、4,
  //   5は0にする。
  ALED(uint8_t ch, uint16_t ledCount1, uint16_t ledCount2, uint16_t ledCount3 = 0,
       uint16_t ledCount4 = 0, uint16_t ledCount5 = 0)
      : ch(ch) {
    ledCount = 0;
    ledCounts[0] = ledCount1;
    ledCounts[1] = ledCount2;
    ledCounts[2] = ledCount3;
    ledCounts[3] = ledCount4;
    ledCounts[4] = ledCount5;
    for (uint8_t i = 0; i < maxCh; i++) {
      ledCount += ledCounts[i];
    }

    // バッファー初期化
    sendBuf = new uint8_t[ledCount * 3];
    for (uint16_t i = 0; i < ledCount * 3; i++) {
      sendBuf[i] = 0;
    }

    // スクランブル初期化
    scr = new uint16_t[ledCount];
    for (uint16_t i = 0; i < ledCount; i++) {
      scr[i] = i;
    }

    reset();

    group = true;  // グループ化フラグセット
  }

  // デストラクタ 終了時の処理
  ~ALED() {
    delete[] sendBuf;  // バッファーをメモリから破棄
    delete[] scr;      // スクランブルをメモリから破棄
  }

  // 変数をリセット
  //   sendBufとscrは変更しない
  //   on : trueでval=100.0 (点灯), falseでval=0.0 (消灯) にセットする
  virtual void reset(bool on = true) {
    pattern = patGrad;
    color.hue = 0.0f;
    color.sat = 100.0f;
    color.val = 100.0f;
    colorPattern.hue = 0.0f;
    colorPattern.sat = 0.0f;
    colorPattern.val = 0.0f;
    colorChange.hue = 0.0f;
    colorChange.sat = 0.0f;
    colorChange.val = 0.0f;
    pos = 0.0f;
    posChange = 0.0f;
    val = on ? 100.0f : 0.0f;
    valChange = 0.0f;
    repeat = 1;
  }

  // バッファーのデータをデバイスに送信
  void sendLedData() {
    if (group) {
      // グループ化されている場合は各チャネルをそれぞれ送信
      uint16_t start = 0;
      uint16_t index = 0;  // ledCounts配列のインデックスカウンター
      uint8_t mask = 1;
      for (uint8_t i = 0; i < maxCh; i++) {
        if (0 != (mask & ch) && ledCounts[index] > 0) {
          genWaveform(mask & ch, start, ledCounts[index] * 3);
          start += ledCounts[index] * 3;
        }
        index++;
        mask = mask << 1;
      }

    } else {
      // グループ化されていない場合は全チャネルに同じデータを送信
      genWaveform(ch);
    }

    delayMicroseconds(350);  // 全てのデータ送信後はしばらくLOWにする
  }
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

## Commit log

2023-02-11 First Release
    量産基板対応でデータ公開を開始
    [MSX_GamingLED - Bottom Copper (Resist).gbr, MSX_GamingLED - Bottom Copper.gbr, MSX_GamingLED - Drill Ident Drawing - [Through Hole].gbr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]
2023-02-13 Update MSXGAMINGLED.ino
    新コマンドを追加
    cmd_cl_p_rgb/cmd_cl_p_hsv
2023-02-14 Add new cmd No32-35
    サンプルプログラムの追加：
    z88dkで作成したMSXDOSからControlするサンプルを追加しました。
    Arduinoプログラム更新：
    10LEDのデータを一括送信できるCMDを追加しました。
    割り込みフラグのハンドリング処理を変更しました。
    Document：
    新コマンドを追記しました。
    その他Typos修正
    [MSXGAMINGLED.ino, main.c]
2023-02-15 Add MSX Gaming LED Logomark
    MSX Gaming LEDのロゴを追加しました。
2023-02-16 Update MSXLEDLOGO.pdf
    データのOutline化をしました
2023-02-20 Update EXBASIC V1.30 & Arduino firmware V1.5
    MSXGAMINGLED.ino:LEDAの演算処理の計算式が誤っていたので修正
    EXBASIC.ROM:_LEDPT_RGB/_LEDPT_HSV命令を追加,DRAW系CMDに送信後WAIT処理を追加
    SampleApplication: BASICの命令サンプルを追加
    GALAXY.BAS：LEDの初期化が足りなかった問題を修正
    [LEDTEST.BAS, MSXGAMINGLED.ino, main.c]
2023-02-25 Add Assembly manual
    AssemblyManual:組み立て説明書を追加
    EXBASIC.ROM:_TESTのコードをpatchで壊していたのを修正
    その他:画像ファイルや説明を追加
    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
    [MSXGAMINGLED.ino]
2023-02-25 Update led_exbasic.md
    V1.40で追加された拡張命令の内容を追加
2023-03-09 Update README.md
    販売URLを追加しました。
2024-05-05 Changed parts list for 2nd lot.
    2ndロットの一部はEPROMの型番が変更があったため、記述を変更
